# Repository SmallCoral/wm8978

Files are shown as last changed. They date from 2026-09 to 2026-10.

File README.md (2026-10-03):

# WM8978 USB 声卡

基于 **ATSAMD21E18A** 和 **WM8978** 的 USB 音频硬件项目，目标支持 **48 kHz / 16-bit 全双工音频**，提供耳机播放、麦克风采集和扬声器输出。

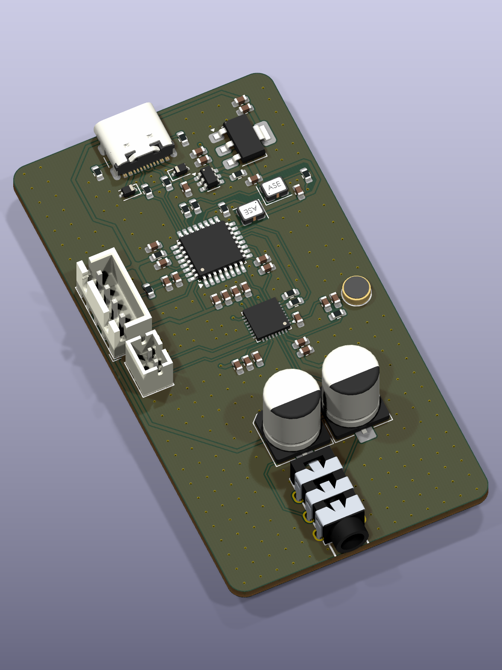
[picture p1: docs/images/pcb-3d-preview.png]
PCB 3D 预览


## 硬件特点

- USB-C 供电与通信，包含 ESD 保护、限流和 3.3 V 稳压。
- SAMD21 与 WM8978 通过 I²S 传输音频，通过 I²C 配置 codec。
- 独立的 12 MHz 主控时钟与 12.288 MHz 音频时钟。
- 立体声耳机输出、驻极体麦克风输入、BTL 扬声器输出及 SWD 调试接口。
- 提供 KiCad 原理图、PCB、自定义库和项目 3D 模型。

## 打开工程

安装 **KiCad 10** 及其标准符号、封装和 3D 模型库，然后打开 [WM8978.kicad_pro](pcb/WM8978.kicad_pro)。项目自定义库与模型使用相对路径。

## 目录

| 目录 | 内容 |
| --- | --- |
| [pcb/](pcb/) | KiCad 工程、原理图、PCB 与器件库 |
| [scripts/](scripts/) | 原理图检查、PCB 同步与模型处理脚本 |
| [reports/](reports/) | 设计复核记录与导出资料 |

## 项目状态

目前处于硬件验证阶段，USB 音频固件与实板测试尚未完成。

[原理图预览](reports/project-snapshot/2026-09-23/WM8978.pdf) · [设计检查记录](reports/footprint-binding/2026-10-03/review.md) · [3D 模型说明](pcb/WM8978.3dshapes/README.md)

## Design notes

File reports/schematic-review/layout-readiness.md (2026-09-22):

# Layout 前设计复核 · 2026-09-22

**此报告对应此前的原理图版本。** 后续文件已变化，最新复查发现 MCLK 断网，ERC 为 1 错误、1 警告；当前结论与证据见 [recheck-current.md](recheck-current.md)。以下“连接通过”和旧文件哈希仅适用于历史版本。

结论：原理图的连接检查通过，可以开展模块预布局；目前不建议直接冻结原理图并完成布线。应先解决 CN2 封装机械孔缺失，确定关键器件实物型号与封装，并明确 MCU 硅版本、上电浪涌和时钟负载。下文区分已发现的问题与尚待验证的风险。本轮未修改原理图、封装库或 PCB。

## 已通过的检查

- KiCad 10.0.5 原生 ERC：0 错误、0 警告，沿用现有规则。
- 200 项网表/参数检查通过，覆盖 MCU、USB、音频、供电和旧网络连接对比。
- 48 个器件的封装均可找到；符号引脚编号与封装电气焊盘编号集合全部对应。见 `layout-pad-check.json`。此检查不证明机械尺寸、定位孔或焊接工艺正确。
- 本轮审查对象原理图 SHA-256：`8368a36561a5d1e1f5fe6f73df535474cd44316d12db75493afdf71000d47e18`。
- PCB SHA-256：`fe49a5879a41e8960b2d1fa32fe4746d4188ac50d7024b465eacbf6cd71d87dd`，与修改原理图前一致。旧 STM32 PCB 仍不能代表本方案。

## Layout 前应解决或确定

### 1. CN2 定位孔缺失：已发现的封装问题

CN2 指定 `WM8978-import-fps:AUDIO-TH_PJ-3136-B`。当前封装有六个电气通孔焊盘，但没有机械定位孔；所附 XKB PJ-3136 图纸标有两个直径 1.60 mm 的定位孔。若采购该图纸所示器件，存在定位柱无法插入 PCB、器件不能贴板的风险。

应先按最终采购的 PJ-3136-B 图纸核对定位柱、引脚孔、插口相对板边的位置，再修正封装。不能只依靠焊盘 2/3/4 与符号对应来放行。

依据：[CN2 所附 XKB 原厂机械图](https://atta.szlcsc.com/upload/public/pdf/source/20231101/FB45AABFD04C0979FDEE8A028D0B6336.pdf)，PJ-3136 俯视图。

### 2. USB2、C86/C87、U16 的实物型号与封装尚未闭环

- USB2 只有通用 `USB_TYPE-C-16P` 封装，无可核对的制造商型号或图纸。不同 16P Type-C 座的固定脚、定位柱和舌片位置并不相同。先确定具体料号，再核对封装。
- C86/C87 为 220 µF / 16 V，分配 `CP_Elec_6.3x5.8`，但未给出有效的制造商型号。应落实容量、额定电压、直径、高度和推荐焊盘；若改变容量，需同步重新确认封装。
- U16 当前写 `WM8978GEFL/RV`，使用中心焊盘 3.1 × 3.1 mm 的通用 QFN。所引用 Rev 4.5 手册对应的更新订货码为 `WM8978CGEFL/...`，封装裸露焊盘 D2/E2 标为 3.30–3.60 mm。必须用实际订货后缀对应的机械图和推荐 land pattern 核对。器件裸露金属尺寸不等于 PCB 推荐铜皮尺寸，因此这里不能仅凭两者不同断言封装不可用。

依据：[WM8978 原厂数据手册 Rev 4.5](https://www.mouser.com/datasheet/2/76/WM8978_v4_5-1141768.pdf)，封装图与修订记录。

### 3. U1 必须避开不支持当前 I²S 架构的硅版本

本图是 WM8978 输出 BCLK/LRCLK，SAMD21 作为 I²S 从机。Microchip 勘误 DS80000760M §1.10.2、§1.10.4 指出：硅版本 A 的 I²S 不工作；硅版本 B 的外部 SCK/FS 从机模式不工作。型号 `ATSAMD21E18A` 中的末尾 A 并不是硅版本 A。

采购和固件验收应排除上述 A/B 硅版本，并通过 DSU.DID 确认。对于本型号，表中列出的后续硅版本为 C、D、H。C/D 的接收数据槽 RIGHT 对齐还有 §1.10.7 限制；建议统一使用 32-bit 时隙承载 16-bit 音频、BCLK = 64 × 48 kHz = 3.072 MHz，并按实际硅版本实施勘误规避。该对齐限制指 MCU 内部 SLOTADJ 配置，不能与 codec 的总线格式混为一谈。

依据：[Microchip SAM D21/DA1 勘误](https://ww1.microchip.com/downloads/aemDocuments/documents/MCU32/ProductDocuments/Errata/SAM-D21DA1-Family-Silicon-Errata-and-Data-Sheet-Clarification-DS80000760.pdf)，器件修订表及 §1.10。

### 4. USB 上电浪涌需要设计余量

直接接 VBUS 的 C75/C77/C92/C93 标称合计 9.6 µF，已经接近传统 USB 热插拔 10 µF 等效负载参考；3V3 端另有约 39.91 µF 的直接去耦容量，LDO 启动也会从 VBUS 取电。应考虑容差、直流偏压、LDO 启动和 codec 上电状态。

建议在电源入口预留/采用受控上升时间、合适限流值的负载开关，或通过计算和波形测量证明现有方案满足目标 USB 端口要求。直接挂在 VBUS 上的电容应留足余量。下游电容不能简单与输入电容相加判定违规；本项是尚未验证的浪涌风险。扬声器如需增加储能电容，宜放在受控电源之后，并核算压降和瞬态电流。

依据：[TI USB 电源分配应用说明 SLVA049](https://www.ti.com/lit/an/slva049/slva049.pdf)，10 µF / 44 Ω 热插拔负载及端口压降讨论。

### 5. Y1 的双负载时钟应核算驱动余量

Y1 ASE 系列规格列出的 CMOS 负载为 15 pF；WM8978 数字输入电容列为 10 pF，目前还同时驱动 MCU XIN，加上走线和焊盘寄生，余量需要确认。

现有 R73=33 Ω 可用于抑制边沿振铃，但不会消除容性负载。若无法证明满足 Y1 输出时序，选择更高负载能力的振荡器或加时钟缓冲器；若保留双分支，预留各分支源端串阻并缩短分支，首板测两端电平、边沿及过冲。增加串阻本身不能作为驱动能力不足的补救结论。

依据：[Abracon ASE 数据手册](https://abracon.com/Oscillators/ASEseries.pdf)及 [WM8978 数字输入规格](https://www.mouser.com/datasheet/2/76/WM8978_v4_5-1141768.pdf)。

## 建议的可选优化

| 改进 | 对本设计的价值与取舍 |
| --- | --- |
| U16 AVDD 支路预留 0 Ω / 磁珠位置 | 便于首板定位数字噪声耦合；配合芯片近端去耦，选择磁珠时检查压降和谐振。保持连续地平面，控制扬声器回流路径。 |
| BCLK、LRCLK 预留源端串阻 | 在 WM8978 输出端预留可调位置，可从 22–47 Ω 范围结合波形调整；短线不一定必须装高阻值。 |
| 增加调试测试点 | 5V、3V3、VDDCORE、RESET、MCLK、BCLK、LRCLK、SDA、SCL 及邻近 GND；高速时钟测试点采用小焊盘、短支路。 |
| 按耳机阻抗选择 C86/C87 | 理想一阶估算，220 µF 配 32 Ω 的截止频率约 22.6 Hz，配 16 Ω 约 45.2 Hz。若目标包括 16 Ω 耳机且重视低频，可选 470 µF，截止约 21.2 Hz；同时评估体积、容差和上电静音/爆音。 |
| 完整物料字段与保护方案 | 补齐 SW1 等器件 MPN、MLCC 耐压/介质及有效容量；按外壳和使用环境确定 VBUS、耳机接口保护。 |

## 放行条件与首板验证

正式 layout 前至少完成 CN2 封装修正、关键器件料号/封装确认、MCU 硅版本约束，并确定浪涌与时钟负载的处理方案。完成后可重新导出网表、跑 ERC 并进入完整布局布线。

现有方案尚无固件或实板证据。首板重点验证 USB 枚举/挂起/恢复、双向 I²S 连续收发、USB 音频速率匹配、扬声器最大工作点的电流和温升，以及麦克风底噪、耳机低频和爆音。原有 `review.md` 的连接检查结论仍有效，但不能替代本记录的 layout 放行条件。

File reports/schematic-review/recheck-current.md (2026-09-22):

# 当前原理图复查 · 2026-09-22

**结论：当前版本不能直接进入正式 layout。** 新发现 WM8978 的 MCLK 断网；CN2 耳机座的机械定位孔问题仍未解决。本轮为检查与记录，未修改原理图、PCB、封装库或项目设置。

## 本次重新执行的检查

- KiCad 10.0.5 重新导出当前网表，并执行原生 ERC：**1 个错误、1 个警告**，均由 codec MCLK 断网引起。
- 对比上次网表：排除旧 J1 / 新 J2 后，178 个共同引脚中，175 个引脚的连接组不变；另外 3 个引脚的差异全部属于同一处 MCLK 网络分裂。
- J2 的 4 个引脚单独检查通过：1=3V3/VTref、2=SWDIO、3=SWCLK、4=GND。
- 48 个器件的封装均存在，符号引脚与电气焊盘编号集合对应；SW1 新封装的两个焊盘也对应。该检查不覆盖机械定位孔及实际采购器件的尺寸。
- 已查看本次原生导出的整页图面，确认时钟源侧缺少网络标签。
- 旧 `scripts/check_schematic.py` 在 `U1.15 -> I2S_MCLK` 检查失败；它还使用旧 J1 接口约束，不能再把此前的“200 项通过”当作本版结论。

证据：`recheck-current-erc.json`、`recheck-current-netlist.xml`、`recheck-current.json`、`layout-pad-check.json`。

## 正式 layout 前的明确修正项

### 1. 恢复 R73 输出到 WM8978 MCLK 的网络

当前网表是：

| 网络 | 实际成员 |
| --- | --- |
| `Net-(U1-PA14)` | R73.2、U1.15 |
| `/I2S_MCLK` | 只有 U16.11 |

因此 Y1 经 R73 只给 MCU 提供时钟，codec 没有 MCLK；按本设计的 PLL / I²S 主机架构，音频时钟不能正常建立。ERC 对应 `pin_not_driven` 和 `isolated_pin_label`。

修正方式：在 **R73.2 至 U1.15 的导线上**恢复 `I2S_MCLK` 标签，使 `R73.2 / U1.15 / U16.11` 成为同一网络；不要用 PWR_FLAG 或忽略 ERC 消除提示。修正后重新导出网表、验证这三个引脚同网。

### 2. CN2 机械定位孔仍缺失

当前指定的 `AUDIO-TH_PJ-3136-B` 封装只有六个电气通孔焊盘，没有机械定位孔。CN2 所附图纸的 PJ-3136 视图要求两个 Φ1.60 mm 定位孔。按该图纸采购的带定位柱器件存在无法贴板安装的风险。

应按最终采购型号核对机械图并修正封装，核对插口与板边位置。[XKB 原厂图纸](https://atta.szlcsc.com/upload/public/pdf/source/20231101/FB45AABFD04C0979FDEE8A028D0B6336.pdf)

### 3. 落实关键实物料号与封装

USB2 仍只有通用 16P Type-C 封装，C86/C87 仍只有 220 µF / 16 V 参数而无有效制造商型号。应先确认实际接口机械尺寸、电解电容直径/高度/焊盘。

U16 仍写 `WM8978GEFL/RV`，使用中心焊盘 3.1 × 3.1 mm 的通用 QFN；引用的 Rev 4.5 手册包含更新的 `WM8978CGEFL/...` 订货码及封装图，应按实际后缀核对。封装裸露金属尺寸与 PCB 铜皮尺寸不能直接等同，不能仅凭名称判断兼容性。[WM8978 手册](https://www.mouser.com/datasheet/2/76/WM8978_v4_5-1141768.pdf)

## 设计改进建议

| 项目 | 建议及优先级 |
| --- | --- |
| 下载接口 | 当前 J2 四针信号接线正确，但没有 RESET。建议增加 RESET 引脚或紧邻接口的复位测试点，以便调试器控制复位；四针 SWD 本身并非接线错误。J2 实际封装是 JST XH 2.50 mm，自制转接线应按上述针序，不能只凭“JLINK”名称接标准排线。 |
| USB 上电浪涌 | VBUS 直接电容仍合计约 9.6 µF，3V3 端直接去耦约 39.91 µF。建议确认启动电流与主机端口要求，必要时增加限流/受控上升时间的负载开关。下游电容不能简单与输入电容相加判定违规。 |
| 时钟驱动 | 修复 MCLK 后，Y1 将恢复同时驱动两个芯片。ASE 规格负载为 15 pF，WM8978 数字输入电容列为 10 pF；需计入 MCU XIN 和走线寄生。若余量不足，应选择驱动能力更高的振荡器或缓冲器。串阻可改善振铃，不能代替负载能力核算。 |
| MCU 硅版本 | 当前 I²S 从机架构应排除 SAMD21 硅版本 A/B；型号末尾 A 不是硅版本。通过 DSU.DID 验收，按勘误处理数据槽对齐；32-bit 时隙承载 16-bit 音频是可采用的配置。 |
| 音频供电与调试 | AVDD 支路预留 0 Ω / 磁珠位置，保持连续地平面并控制扬声器回流；BCLK/LRCLK 源端预留可调串阻，增加电源及关键时钟测试点。 |
| 耳机低频 | C86/C87=220 µF 配 16 Ω 耳机的理想一阶截止约 45.2 Hz，配 32 Ω 约 22.6 Hz。若重视 16 Ω 耳机低频，可考虑 470 µF，同时核对体积和上电爆音控制。 |

供电、时钟和硅版本依据：[TI USB 热插拔负载说明](https://www.ti.com/lit/an/slva049/slva049.pdf)、[Abracon ASE 规格](https://abracon.com/Oscillators/ASEseries.pdf)、[WM8978 数字输入规格](https://www.mouser.com/datasheet/2/76/WM8978_v4_5-1141768.pdf)、[Microchip 勘误 §1.10](https://ww1.microchip.com/downloads/aemDocuments/documents/MCU32/ProductDocuments/Errata/SAM-D21DA1-Family-Silicon-Errata-and-Data-Sheet-Clarification-DS80000760.pdf)。

## 本轮文件基线

当前文件已经与上次审查版本不同，本轮保留用户的后续修改，没有回退 PCB。

| 文件 | 本轮开始及结束时 SHA-256 |
| --- | --- |
| 原理图 | `da9090cd18255e0a34c1a41e4236d26b039e8611c06d62f0447b395383ad4108` |
| PCB | `3dbe479590fec1b7c73a3aa50047f6be0c3d2642301092d8fa0e42d8cbf08127` |
| 项目设置 | `a735b4348fb94e4a48c6c9c1843c64e70f60052514bbe274a237ced6aaafd8e3` |

本轮未验证 PCB 布局布线、固件或实板。此前报告保留为历史记录；当前放行结论以本文件及对应 SHA-256 为准。

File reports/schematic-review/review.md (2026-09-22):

# 原理图复核记录 · 2026-09-22

后续 layout 审查发现了机械封装和器件版本等待解决事项，详见 [layout-readiness.md](layout-readiness.md)。本记录的 ERC/连接通过不代表已满足完整 layout 放行条件。

## 设计基线

工作开始时，用户已经删除旧 STM32 主控电路并放入未接线的 ATSAMD21E18A-A。
本次沿用该选择和现有 USB/WM8978 电路，未从 Git 恢复旧原理图。
保留所有原有器件 UUID，仅调整部分文字位置并补充主控外围。

原生 ERC 初检 45 项；最终 0 错误、0 警告。检查器仍使用原项目规则，没有新增排除或降低严重度。
原项目忽略的类别仍是 single_global_label、four_way_junction、simulation_model_issue、footprint_filter，详见 ERC JSON。

## 硬件修正

1. 完成 U1 的供电、所有地脚、USB FS、双向音频数据、I²C、复位和 SWD。
2. 新增 C97–C103、R70–R74、Y1、SW1、J1，共 15 个器件。
3. 使用独立 12 MHz 参考驱动 MCU XIN 和 codec MCLK，避免直接把 MCU 48 MHz 整数分频误当成 12.288 MHz。
4. 时钟 EN 接 PA18，100 kΩ 默认下拉；支持在切回内部时钟后关断振荡器。
5. 将 U16 的 MICBIAS 输出与 R68 偏置支路连通。原图标签仅存在于电阻一侧，没有给麦克风供电。
6. 更新主控名称、模块分区、说明及部分密集文字。原有 USB/音频器件位置和所有导线保持。

## 电气复核

| 项目 | 结论 |
| --- | --- |
| VDDIN、VDDANA | 同为 3V3，每组 100 nF + 10 µF |
| VDDCORE | 与 3V3 隔离，仅接 1 µF 对地；两个 GND 脚均连接 |
| 复位和调试 | RC 复位、330 Ω 按键串阻、SWCLK 1 kΩ 上拉；标准 Cortex SWD 针序 |
| USB | PA24=D−、PA25=D+；两侧触点并接正确，两路 CC 独立下拉，TVS 对地并联 |
| Codec 控制 | PA22/23 使用 SERCOM3 PAD0/1；4.7 kΩ 上拉；MODE=0，地址 0x1A |
| I²S | PA07=SD0 TX、PA08=SD1 RX；PA10/11 分别接 codec BCLK/LRC；同时收发 |
| 麦克风 | MICBIAS→R68→MIC1 正极；C79 接 LIP，C80 将 LIN 交流接地 |
| 耳机 | 两个 220 µF 电容正极朝向 codec，输出与直流偏置隔离 |
| 扬声器 | ROUT2 与 LOUT2 分别接负载两端，不接地；需固件配置 BTL 信号及反相 |
| 不使用的 codec 引脚 | 保留现有 NC，固件关闭不用的输入/输出通道 |

## 固件约束

- 启动顺序：OSC8M 启动 → PA18 置高 → 等待至少 2 ms → XOSC 外部时钟模式 → 配置 MCU/USB 时钟。
- USB 必须得到符合规格的 48 MHz 时钟并加载芯片 USB pad 校准值。
- WM8978 以 12 MHz 为 PLL 输入，参考参数 N=8、K=0x3126E9、PLLPRESCALE=0、MCLKDIV=/2；再选择 BCLK 分频、字长和 48 kHz 帧率。
- codec 为音频主机，SAMD21 的 serializer 0 发送、serializer 1 接收，共用 clock unit 0 的外部 BCLK/FS。不能把 PA07、PA08 都配置成输出。
- USB 主机 SOF 和板上音频参考并不锁相，需要异步反馈及持续的 DMA 缓冲管理；录音端也须正确管理每帧样本数。
- CSB 接地，不能把 GPIO1 配置为推挽高电平输出。
- 挂起时先使 codec 进入低功耗、MCU 切回内部时钟，再拉低 PA18。唤醒按相反方向建立时钟，并等待稳定。
- 未枚举和挂起时限制功耗，扬声器输出需按可用 USB 电流预算限幅。不能把 1 W 额定输出当作所有主机端口都允许的工作点。

## 检查证据

- `erc.json`：KiCad 10.0.5，所有错误、警告、排除项均纳入输出，违规数为零。
- `netlist.xml`：KiCad 从最终原理图直接导出。
- `connectivity-check.json`：200 项检查通过，包括关键引脚/参数、未使用 GPIO、完整旧电路连接对比。
- 旧连接对比允许的唯一网络合并：`R68.1 + U16.32 + C96.1`，对应 MICBIAS 修复。
- 原生 SVG 导出后另用原生 PDF/Poppler 做图面检查，检查了新增主控区和密集 codec 标注。
- PCB SHA-256：`fe49a5879a41e8960b2d1fa32fe4746d4188ac50d7024b465eacbf6cd71d87dd`，修改前后一致。
- 项目设置 SHA-256：`fc729af468ccccd9d76b9b11aee179896fd4961858aca257d9ce4f9314589901`，修改前后一致。

## 保留的实际验证事项

尚未运行固件或实板测试。USB 信号质量、ESD、挂起电流、LDO 温升、振荡器双负载与走线电容、
音频噪声和最大输出功率须在后续实板确认。现有 USB 外壳直连 GND，VBUS 无独立 TVS；
是否增加屏蔽 RC 或 VBUS 保护应结合外壳接地及产品 EMC 要求确定。
本次不更新 PCB；旧 STM32 PCB 和四份旧参考原理图均不代表当前正式电路。

器件与引脚依据见仓库 README 的厂商数据手册链接。

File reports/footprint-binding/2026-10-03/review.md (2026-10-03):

# 封装关联与原始 3D 模型补齐

2026-10-03 使用 KiCad 10.0.5 核对正式工程的 54 个实体器件，完成剩余关联，并用原始 CAD 替换此前生成的简化参考模型。

## 完成的修改

- C97、C98、C99、C100 的封装本身已经存在且与原理图选型一致，但原 PCB 缺少对应符号的 UUID 路径。本次补齐四条关联。
- Y1、Y2 使用 Abracon ASE 原厂 STEP，MIC1 使用当前封装关联的立创原库 STEP；这些下载文件未作修改。
- CN2 按用户确认的五脚版本保留现有五个金属插脚孔与两个定位孔。取得的原厂、原库 CAD 都有六个金属插脚，因此绑定立创原库的五脚适配模型：只切除多余中部插脚在安装面以下的部分，保留主体及触点细节，另存未经修改的六脚原库文件。适配文件不标为原厂五脚 CAD。
- MIC1、CN2 的项目封装库同步保存模型路径。Y1、Y2 使用项目库中的同名振荡器封装，焊盘及图形保持原样，后续更新封装时也能保留模型引用。
- 新增模型使用 `${KIPRJMOD}` 相对引用，文件随仓库保存。其余 50 个器件使用 KiCad 10 标准 3D 库。

详细来源、坐标偏移及适配范围见 [模型说明](../../../pcb/WM8978.3dshapes/README.md)。

## 验证结果

| 检查 | 结果 |
| --- | --- |
| 原理图封装字段、库文件、PCB 封装标识及符号关联 | 54 / 54 通过 |
| PCB 3D 模型路径 | 54 / 54 文件存在 |
| 三个原始 STEP 的字节与下载 SHA-256 比较 | 相同 |
| 三个原始 STEP 和一个五脚适配 STEP 重新读入 | 全部有效 |
| KiCad 原生 3D 渲染、整板 STEP 导出 | 成功，已检查显示与方向 |
| 整板 STEP 中 MIC1 / CN2 的板下金属引脚截面 | 2 / 5 根，与现有钻孔对齐 |
| 整板 STEP 中 ASE、CN2 的安装高度 | 正确 |
| 原理图完整网络及引脚集合与修改前比较 | 相同 |
| 35 项关键电路拓扑检查 | 全部通过 |
| 原生 ERC | 0 错误、0 警告 |
| 原生 DRC 未连接项 / 原理图一致性问题 | 0 / 0 |

模型替换以本地 KiCad 最新存档（2026-10-03 02:13:00，历史提交 `3530e5bf584c00aeff92c27b3be9be7ed7e63d87`）为布局基线。与该存档比较，全部原生几何相同：54 个封装、254 段走线、285 个过孔、3 个铺铜/禁铺铜区。文件语义比较确认，最新存档中的模型绑定、焊盘、网络、布线、板框、铺铜与工程规则均完整保留。此前的模型替换只修改 Y1、Y2、MIC1、CN2 的模型引用和偏移。

该最新存档相对上次 GitHub 提交已调整 C97、C98 的 X 坐标（分别从 127.76、126.25 mm 改为 129.00、127.49 mm），并将 R71 的 X 坐标从 123.25 mm 改为 124.75 mm，调整其 +3V3、SWCLK 走线及铺铜填充。这些已有布局调整一同保留。原理图相对上次 GitHub 提交仅改动 Y1/Y2 的封装库名称。

当前 DRC 仍有原先的 402 个错误、3 个警告，各类型及严重程度的计数与上次检查相同。关联及模型补齐不代表制造检查已经清零；原有规则与孔距、丝印事项见 [PCB 复核](../../pcb-review/2026-10-02-recheck-2347/review.md)。

原始模型及五脚适配后的 3D 预览

## 检查记录

- [封装关联](binding-audit-after.json)、[3D 模型路径](models-audit-after.json)
- [原始模型来源](original-model-sources.json)、[CAD 与原生整板 STEP 验证](original-model-validation.json)
- [五脚适配检查](five-pin-adaptation.json)、[模型绑定变更](model-binding-changes.json)、[修改范围验证](verification.json)
- [ERC](erc.json)、[DRC](drc.json)、[关键拓扑](topology-check.json)
- [原生网表](netlist.xml)、[几何数据](geometry.json)

源文件 SHA-256：

```text
PCB: 5fb48f70224364015cf48c9607fd8780e6c241d2294cacb238a3a9f37e3e6dfc
SCH: ec997bf1890f5b327d74b67f1542f2626916010a5ec2dfd338209763c5ab9a2f
```

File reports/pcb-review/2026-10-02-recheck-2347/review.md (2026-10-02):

# PCB 再次更新后复核 — 2026-10-02 23:47 版本

这版的主要布局修改有效：主控 VDDANA 去耦、codec 时钟输出串阻以及 QFN 底部局部接地都有明确改善，可以保留这些调整。整体功能分区和底层大面积地平面也可以保留。布局已更接近打样，剩下主要是供电路径优化和发板前的制造规则核对。

检查依据为 **2026-10-02 23:47:32 保存的 PCB**。本次仅生成报告，未修改 PCB、原理图或工程设置；三个源文件检查前后哈希相同。本轮使用 KiCad 10.0.5 原生 DRC，在内存中重新铺铜，没有保存回板文件。原理图和工程设置与上一轮内容相同。

## 已完成的改善

| 项目 | 上一轮 | 本轮 | 结论 |
| --- | --- | --- | --- |
| C99 100 nF 到 U1.9 电源脚 | 焊盘中心距离 14.75 mm | **1.71 mm** | 已移到主控右侧电源脚附近，位置明显改善，不再列为远离电源脚的问题。 |
| C100 10 µF | 距 U1.9 1.98 mm | **3.11 mm**，紧邻 C99 | 让 C99 更靠近电源脚的安排合理，不必仅为减小 C100 的直线距离再次交换位置。 |
| U16 BCLK 输出到 R75 之前的铜线 | 11.70 mm | **1.74 mm** | 串阻已靠近 codec 驱动端。 |
| U16 LRCLK 输出到 R76 之前的铜线 | 15.83 mm | **1.65 mm** | 串阻已靠近 codec 驱动端。 |
| U16 QFN EP 内接地过孔 | 0 个 | **9 个** | 局部顶底层接地连接改善，不建议仅为增加数量继续堆孔；核对焊盘内过孔的装配处理。 |
| 未连接项目 / 原理图一致性问题 | 0 / 0 | **0 / 0** | 本轮 DRC 没有发现连接缺失或网表不一致。 |

当前 54 个封装、252 段走线、285 个过孔。C99、C100、R75、R76 和 C80 的位置发生变化；增加了局部地过孔并更新相应走线、地铜。

## 剩下的布局优化

| 优先级 | 位置 | 当前证据与建议 |
| --- | --- | --- |
| 较高 | **3V3 主干与 codec AVDD** | LDO 输出至 U16.31 AVDD 的铜线路径仍约 **138.25 mm**，到 U1.9 仍约 **95.19 mm**。建议改成更直接的主干与本地支路，减少沿板边及耳机电容外围绕行。这是几何路径估算，不能据此断言实板一定产生噪声或压降超标。 |
| 中 | **Y2/R73/C104 → U16 MCLK** | R73 到 U16.11 的铜线仍约 **25.64 mm**，包含两个过孔；Y2 到 R73 另约 4.13 mm。建议将这一组移近 codec 的数字输入侧、避开麦克风区域，同时保留连续地参考。该长度本身不是证明不能工作的依据。 |
| 中 | **C103 → Y1 电源脚** | C103 电源焊盘距 Y1.4 仍约 **6.46 mm**，可进一步靠近。Y1 到 MCU 的约 2.38 mm 时钟线可保留。 |
| 中 | **SPKVDD / BTL 与 codec 旁路** | SPKVDD 仍有靠近芯片的 0.2 mm 局部支路，两根 BTL 输出仍为 0.2 mm。按实际扬声器电流及铜厚核算后尽量加宽；C90、C92 的电源焊盘距对应芯片脚约 5.37 / 5.26 mm，可进一步缩短本地去耦环路。 |

上轮 C99 和 R75/R76 的摆位问题已解决，不应继续把这些旧问题计入当前待改清单。U16 EP 接地过孔也已补上，下一步应确认焊盘内过孔与钢网/回流焊工艺配合。当前设置未声明塞孔或填孔，不能仅凭地孔数量认为装配工艺已经确认。

相关原厂依据：[SAMD21 数据手册的 Schematic Checklist](https://ww1.microchip.com/downloads/en/DeviceDoc/SAM-D21DA1-Family-Data-Sheet-DS40001882G.pdf)、[WM8978 数据手册](https://www.mouser.com/datasheet/2/76/WM8978_v4_5-1141768.pdf)、[Cirrus/Wolfson QFN 应用笔记 WAN_0118](https://statics.cirrus.com/pubs/appNote/WAN_0118_Rev_2.5.pdf)。

## DRC 与制造收尾

本轮原生 DRC 为 **402 个错误、3 个警告**，未连接和原理图一致性均为 0。错误类别与上一轮相同，新增的是一处 C80 与 U16 丝印重叠警告；并未新增普通铜间距违规。

| 类型 | 数量 | 当前证据与处理方式 |
| --- | --- | --- |
| 过孔外径不足 | 199 个错误 | 实际 **285 个过孔全部为外径 0.50 / 孔径 0.30 mm**，工程要求外径 ≥0.60 mm。DRC 列出的数量并不是实际全部违规过孔的数量。 |
| 过孔环宽不足 | 199 个错误 | 实际环宽 0.10 mm，工程要求 ≥0.15 mm。若沿用当前制造规则，应改为 0.60/0.30 mm 后复查间距；若选定板厂明确接受当前规格，再按其工艺能力修订规则。新增 EP 过孔也必须纳入核对。 |
| USB2 封装内部孔距 | 4 个错误 | PTH 地触点与 NPTH 定位孔间距 0.1944 mm，规则为 0.25 mm。核对实际采购的 USB4105-GF-A 图纸及板厂 PTH/NPTH 要求；确认几何及工艺允许后才能使用有依据的局部规则。 |
| CN2 丝印越板边 | 2 个警告 | 调整或裁掉越界丝印；接口实体伸出量按插拔及外壳配合判断。 |
| C80/U16 丝印重叠 | 1 个警告 | 新位置使 C80 外框与 U16 丝印重叠，重叠位置约 `(141.0,98.0) mm`。裁短对应丝印即可，未发现因此产生铜间距错误。 |

制造规则未落实前仍不建议直接发板。398 条过孔错误是重复的尺寸/环宽问题，不代表 398 种独立的电路缺陷。

后续工艺核对补充：按[嘉立创制造工艺要求](https://www.jlc.com/portal/1/serviceGuide)，双层板普通过孔支持内径 0.30 mm / 外径 0.50 mm。因此若选用该板厂相应工艺，可保留当前普通过孔尺寸，并将最小过孔外径、最小过孔环宽分别落实为 0.50 mm、0.10 mm；不必仅为当前 DRC 报错统一放大全部过孔。本次 GitHub 同步未修改 KiCad 工程规则，原始 DRC 结果仍对应检查时的 0.60 mm / 0.15 mm 要求。QFN 焊盘内过孔的装配处理仍需另行确认。

所有器件位号仍隐藏，尚无额外接口文字。发板前建议补必要的芯片位号、SWD 针序、扬声器 BTL 端标识和极性说明。底层地平面整体较完整，可以保留；本轮不建议为了 USB 线长的微小差异加蛇形线。

## 文件与范围

- [原生 DRC](drc.json)、[本轮测量](review-metrics.json)、[本轮与上一轮比较](comparison.json)。
- [当前顶层图](top.png)、[当前底层图](bottom.png)、[顶层 PDF](top.pdf)、[底层 PDF](bottom.pdf)。
- [供电路径估算](power-paths.json)：仅基于走线中心线与焊盘几何；`null` 表示该简化模型未解析出路径，不代表原生 DRC 判断未连接。本轮 DRC 未连接为 0。
- [检查前源文件哈希](source-sha256.json)、[上一轮报告](../2026-10-02-recheck/review.md)。

本轮没有重复运行原理图 ERC，因为原理图内容未改变；上轮原生 ERC 为 0 错误、0 警告。未进行实板音频、USB 信号、热性能或外壳配合测试。

PCB SHA-256：`6bab4104b9a4396aed0626787fb0733c4d03d5ecf8939795109a768cd1f0dbb1`。

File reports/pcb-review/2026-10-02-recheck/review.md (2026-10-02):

# PCB 更新后复核 — 2026-10-02

比上一版有改善，但仍建议完成下面的局部调整和制造规则核对后再发板。整体功能分区及底层大面积接地可以保留，无需整体重排。

本次检查的是 **2026-10-02 21:50:12 保存的 PCB**，使用 KiCad 10.0.5 原生 DRC、重新铺铜后的层图及实际焊盘/走线几何。仅生成检查报告，没有写入 PCB、原理图或工程设置；三份源文件检查前后的 SHA-256 一致。没有可检查的 KiCad 编辑窗口，未确认未保存内容。

## 本次已改善

| 项目 | 上一版 | 当前版本 |
| --- | --- | --- |
| C100 到 U1.9 VDDANA 的焊盘中心距离 | 10.28 mm | **1.98 mm**，移到主控右侧、靠近电源脚 |
| SDA/SCL 与地过孔的铜间距违规 | 2 项，来自 `(133,89) mm` 地过孔 | **0 项**，该地过孔已移除 |
| 未连接项目 / 原理图一致性问题 | 0 / 0 | **0 / 0** |
| 原生 DRC 错误 / 警告 | 404 / 2 | **402 / 2** |

当前为 54 个封装、253 段走线、253 个过孔。与上一版相比，只有 C100 的封装位置发生变化；移除了两个地过孔，修改了 C100 连接及地铜轮廓。原理图、工程设置内容未改变，因此本轮没有重复运行原理图 ERC；上轮 ERC 的结果为 0 错误、0 警告。

## 建议先完成的修改

| 优先级 | 位置 | 当前证据与建议 |
| --- | --- | --- |
| 高 | **C99 → U1.9/10** | C99 是 100 nF，电源焊盘距 U1.9 仍约 **14.75 mm**。C100 移近是有效改善，但本地高频旁路仍应由就近的 C99 配合完成。把 C99 移到 U1.9/10 附近，优先缩短电源脚—电容—地的环路，再安排 10 µF 的 C100。 |
| 高 | **R75/R76 → U16.8/7** | 两颗 33 Ω 电阻仍在 MCU 接收端附近；本设计 codec 为 BCLK/LRCLK 驱动端。串阻之前的铜线仍约 **11.70 / 15.83 mm**。若用于源端串联阻尼，应移近 U16 输出脚，再从电阻往 MCU 布线。 |
| 高 | **3V3 主干及 U16 AVDD** | 实际走线图中的 U15 输出至 U16.31 AVDD 最短铜线路径仍约 **138.25 mm**，到 U1.9 约 **95.19 mm**。从 LDO 建立更直接的供电干线和支路，把电源接到对应去耦及芯片引脚附近，减少沿板边、耳机电容外围的绕行。路径长度仅为几何估算，不代表已经测得噪声或压降。 |
| 中 | **Y2/R73/C104 与 C103** | R73 到 U16 MCLK 仍约 **25.64 mm**，包含两个过孔。建议将 Y2/R73/C104 靠近 codec 数字输入侧。Y1 到 MCU 的 2.38 mm 时钟线可以保留；Y1 旁路 C103 距其 VDD 焊盘约 **6.46 mm**，可再贴近。 |
| 中 | **U16 接地和功率路径** | QFN EP 内仍没有接地过孔，EP 中心距最近地过孔约 **4.51 mm**。建议在 EP 或其紧邻区域增加接到底层地的过孔，焊盘内过孔按装配工艺处理。SPKVDD 的局部 0.2 mm 支路及两根 0.2 mm BTL 输出仍可按扬声器电流、铜厚核算后加宽；C90/C92 等本地去耦可进一步靠近对应脚。 |

去耦位置依据 [SAMD21 数据手册的 Schematic Checklist](https://ww1.microchip.com/downloads/en/DeviceDoc/SAM-D21DA1-Family-Data-Sheet-DS40001882G.pdf)。WM8978 EP 接地及装配建议可对照 [WM8978 数据手册](https://www.mouser.com/datasheet/2/76/WM8978_v4_5-1141768.pdf) 和 [Cirrus/Wolfson WAN_0118](https://statics.cirrus.com/pubs/appNote/WAN_0118_Rev_2.5.pdf)。

## 发板前仍需处理的 DRC

| 类型 | 本轮数量 | 原因和处理方式 |
| --- | --- | --- |
| 过孔外径 | 199 个错误 | 实际 **253 个过孔全部为 0.50/0.30 mm**；工程最小外径为 0.60 mm。报告数量不等同于全部实际违规过孔数量。 |
| 过孔环宽 | 199 个错误 | 当前环宽 0.10 mm，小于工程最小 0.15 mm。沿用现有制造规则时，应改为 0.60/0.30 mm 并复查周围间距；若板厂明确接受当前尺寸，再据其能力修订规则。 |
| USB2 内部孔距 | 4 个错误 | PTH 地触点与 NPTH 定位孔间距 **0.1944 mm**，规则要求 0.25 mm。需对照 USB4105-GF-A 实际采购件图纸及板厂要求核对；确认几何和工艺允许后才能采用适当局部规则。移动普通走线无法解决封装内部孔距。 |
| CN2 丝印到板边 | 2 个警告 | 调整或删除越界丝印。连接器实体伸出是否合理应按插拔和结构要求判断，不必仅因丝印警告移动连接器。 |

这些错误多数是重复的过孔尺寸问题，不是 402 种独立设计缺陷；但在制造规则未落实前，不能据“全部已连接”直接发板。

## 可以保留和最后补充

底层 GND 整体较完整，应继续保留连续参考地。USB D+/D− 的短走线没有新增问题，本轮不建议因微小长度差加入蛇形线；实际阻抗仍取决于板厂叠层。上轮关于 R53/R54 装配值的核对建议仍适用，详见 [上轮报告](../2026-10-02/review.md)。

所有器件位号仍隐藏，尚无额外接口文字。建议至少补主芯片位号、SWD 排针定义、扬声器 BTL 端和必要极性标识。固定方式仍需与外壳配合确认。

本次结论是布局及规则复核，尚未验证实际板厂叠层、外壳、装配条件或实板的音频/USB性能。

## 复核文件

- [原生 DRC](drc.json)、[本轮测量](review-metrics.json)、[与上一版的比较](comparison.json)、[供电路径](power-paths.json)。
- [当前顶层图](top.png)、[当前底层图](bottom.png)、[顶层 PDF](top.pdf)、[底层 PDF](bottom.pdf)。
- [检查前源文件 SHA-256](source-sha256.json)；本轮脚本再次核对了三个源文件未变。

PCB SHA-256：`62d195dd3c062353bcaa066ac836e092f2f920b8582b82d5aec6441b4f7d257a`。

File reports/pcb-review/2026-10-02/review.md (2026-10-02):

# PCB 布局复核 — 2026-10-02

整体分区可保留，建议完成下列局部调整及制造规则核对后再发板。USB/电源在上方、MCU 居中、codec 与模拟输入输出在下方的方向合理；底层保留了大面积 GND，连接已完成。主要问题集中在去耦和时钟外围的摆位、过长的电源路径、过孔规则及接口标注。

本次仅检查及生成报告，未写入 PCB、原理图或工程设置。Windows 当前没有可检查的 KiCad 编辑窗口，因此依据磁盘上正式工程文件检查，没有确认任何未保存的编辑内容。

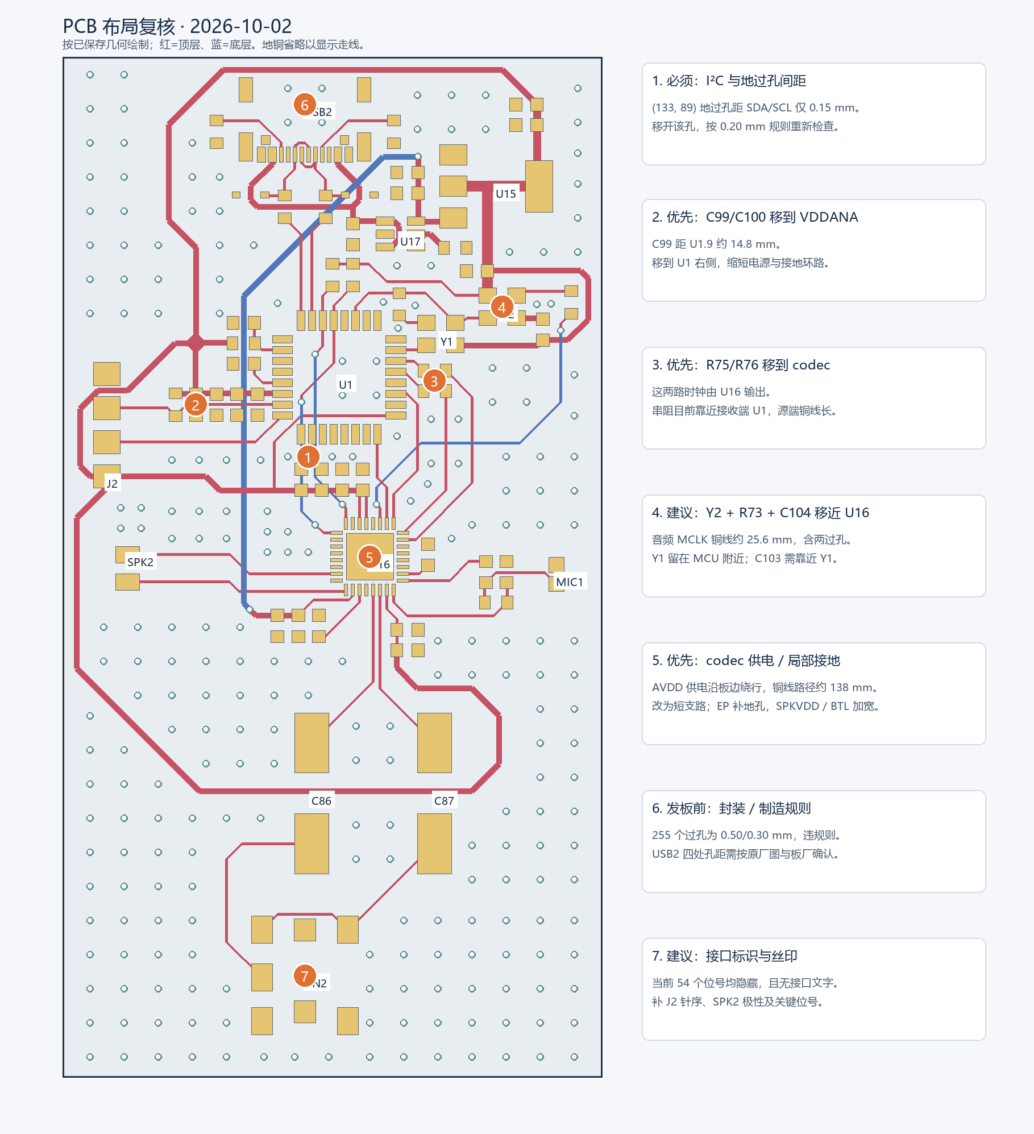
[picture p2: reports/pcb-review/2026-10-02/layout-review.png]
布局复核位置图


图中位置来自 `pcbnew` 对实际 PCB 的读取。红色为顶层走线，蓝色为底层走线；为显示走线路径，复核位置图省略了地铜，焊盘以简化外形表示。原生 KiCad 含地铜导出图见 [顶层](top.svg)、[底层](bottom.svg)。

## 已完成的检查

- KiCad 10.0.5 原生 DRC：报告列出 **404 个错误、2 个警告**；**0 个未连接项目、0 个原理图一致性问题**。
- 分别检查已保存铺铜与在内存中重新铺铜的结果，两份报告一致。没有使用 `--save-board`。
- 原生原理图 ERC：**0 错误、0 警告**；现有脚本的 **35 项关键拓扑检查通过**。
- 54 个封装、251 段走线、255 个过孔，2 层铜；1 个跨顶底层 GND 铺铜区与 2 个振荡器禁铺铜区。板框实体约 39.5 × 74.8 mm。
- PCB、原理图、工程设置的 SHA-256 在检查前后相同。

DRC 的数量大部分是同一类过孔尺寸问题重复产生，并非 404 种独立设计问题。不过仍不能直接忽略违规发板。

## 必须解决的规则问题

| 问题 | 实际证据 | 建议 |
| --- | --- | --- |
| 过孔直径与环宽 | 实际 255 个过孔全部为外径 0.50 mm / 孔径 0.30 mm，环宽 0.10 mm。当前工程要求外径 ≥0.60 mm、环宽 ≥0.15 mm。DRC 分别列出 199 条直径与 199 条环宽错误；几何统计显示全部 255 个过孔都需处理。 | 若沿用现有规则，统一采用 0.60/0.30 mm，并重新检查附近间距；若板厂确认可生产 0.50/0.30 mm，才将实际制造能力落实为项目规则。 |
| I²C 与地过孔间距 | `(133.000, 89.000) mm` 的 GND 过孔与底层 SDA、SCL 各有一处间距仅 0.15 mm，规则为 0.20 mm。 | 优先移动该地过孔；如果同时增大过孔直径，必须重新检查与两根线的距离。 |
| USB2 封装内部孔距 | PTH 地触点与两个 NPTH 定位孔间距 0.1944 mm，小于规则 0.25 mm，因重复地焊盘编号共报 4 项。定位孔中心为 `(129.860, 65.805)`、`(135.640, 65.805) mm`。 | 对照实际采购的 USB4105-GF-A 原厂图与板厂 PTH/NPTH 要求核对。确认几何正确且工艺接受后可设有依据的局部规则；否则调整连接器选型或封装。此项不能靠移动普通走线解决。 |
| CN2 丝印越板边 | 耳机接口前部有 2 条丝印被板边裁切。 | 调整或删除越界丝印；保留连接器为插拔所需的实体伸出量，不能仅根据丝印警告判断应移动连接器。 |

原始报告：[已保存状态 DRC](drc-saved.json)、[内存重新铺铜 DRC](drc-refilled.json)。

## 优先调整的布局

| 优先级 | 位置 | 现状与调整方向 |
| --- | --- | --- |
| 高 | C99/C100 → U1.9 VDDANA | C99 电源焊盘到 U1.9 中心距离约 **14.75 mm**，C100 约 **10.28 mm**。这组器件位于 U1 左侧，而 VDDANA 在右侧。将 C99 移到 U1.9/10 附近，C100 紧邻；100 nF 的电源、地环路优先最短。原理图上同属 3V3 不代表任意位置都能起到同样的高频去耦作用。 |
| 高 | R75/R76 → U16 时钟输出 | WM8978 是 BCLK/LRCLK 的驱动端，现有 R75/R76 位于 U1 接收端附近。U16 到串阻之前的铜线分别约 **11.70 / 15.83 mm**。将它们移到 U16.8/7 出脚附近，再从串阻往 U1 布线，以实现源端阻尼。 |
| 高 | 3V3 干线与 codec AVDD | 3V3 沿上边、左边、耳机电容外围有大段绕行。按实际走线中心线和焊盘连接建立图，U15 输出到 U16.31 的最短铜线路径约 **138.25 mm**；到 U1.9 约 95.19 mm。建议从 LDO 建立更直接的干线，分别接 MCU 和 codec 电源去耦，再进入对应引脚。AVDD 支路不宜为了避线而绕过整片耳机输出区域。此长度是几何路径，不是电源阻抗或噪声实测。 |
| 中 | Y2、R73、C104 → U16 | Y2→R73 铜线约 4.13 mm，R73→U16 MCLK 铜线约 **25.64 mm**，共约 29.77 mm，后半段含两个过孔及较大绕行。将这一组移近 U16.11，尽量在顶层短接，底层保留参考地。Y1 当前到 U1.XIN 约 2.38 mm，可保留。 |
| 中 | C103 → Y1 VDD/GND | C103.1 到 Y1.4 的焊盘中心距离约 **6.46 mm**。应把这颗旁路电容贴近 Y1 的电源和地；移动 Y2 时不要把 Y1 的本地旁路也带走。 |
| 中 | U16 EP 与电源外围 | EP 范围内没有地过孔，EP 中心到最近 GND 过孔约 **4.51 mm**。建议在 EP 或其紧邻区域补局部接地过孔，把顶层局部地直接接到底层地；焊盘内过孔与钢网开口按装配工艺共同设计。C90 到 DCVDD、C92 到 SPKVDD 的焊盘中心距离分别约 5.37 / 5.26 mm，均可进一步靠近，C83/VMID 也可缩短。 |
| 中 | SPKVDD、SPK2 BTL 输出 | SPKVDD 从限流器到 codec 的铜线路径约 53.71 mm，主干 0.4 mm，但靠近 C92/U16 有约 5.04 mm 的 0.2 mm 支路。两根 BTL 输出均为 0.2 mm、约 16 mm 长。建议按目标扬声器电流和铜厚核算，加宽到布局可容纳的宽度，短接本地去耦；0.4–0.6 mm 可作为此板普通支路的起点，并非已经验证的载流或温升结论。 |

SAMD21 手册明确要求去耦贴近每组电源引脚；串阻位置建议依据本设计的 codec 主机方向。WM8978 数据手册要求 QFN 地焊盘接模拟地，其引用的封装应用笔记说明了连接底层地的热过孔与钢网处理。[SAMD21 数据手册，Schematic Checklist](https://ww1.microchip.com/downloads/en/DeviceDoc/SAM-D21DA1-Family-Data-Sheet-DS40001882G.pdf)、[WM8978 数据手册](https://www.mouser.com/datasheet/2/76/WM8978_v4_5-1141768.pdf)、[Cirrus/Wolfson WAN_0118](https://statics.cirrus.com/pubs/appNote/WAN_0118_Rev_2.5.pdf)。

## 可以保留与补充的地方

USB D+/D− 当前同在顶层，R53/R54 到 MCU 的铜线分别约 8.01 / 7.93 mm，差值很小。这是一块全速 USB 板，优先保持短、并行、连续参考地，不需要为了微小长度差增加蛇形绕线。现有约 0.20 mm 线宽与约 0.60 mm 间隙没有在工程中形成差分阻抗规则；不能据此声称已经满足 90 Ω，需要按实际板厂叠层和相邻地铜核算。

R53/R54 当前为 22 Ω，另有一项装配值建议复核：Microchip 针对 SAMD21 的 PCB 指南说明 USB 接口已设计匹配阻抗，不需要额外串联终端电阻。建议保留封装作为可调位置，优先复核采用 0 Ω 的装配方案，再用 USB 波形/功能测试确认。此次没有改变电阻值或原理图。[Microchip PCB Layout and Manufacturing Recommendations](https://onlinedocs.microchip.com/oxy/GUID-D5B5915F-6907-409C-A6D9-F79690ACDCA3-en-US-1/GUID-05FBCAE8-7963-4832-B376-55381CE331FD.html)。

底层 GND 整体较完整，麦克风支路与 BTL 输出分别在 codec 两侧，这些可以保留。将振荡器移近 codec 时，应选数字输入侧，避开 MIC1/C79/R68 的麦克风区域；不要为了分离模拟、数字信号而切开公共地平面。

当前 54 个器件的 Reference 均隐藏，PCB 没有额外接口文字。建议至少补上 U1/U16/Y1/Y2 的位号、J2 的 `1=3V3 / 2=SWDIO / 3=SWCLK / 4=GND`、SPK2 的两个 BTL 端标识及接口名称。核对电解极性及 IC Pin 1 标识装配后是否可见。该板没有安装孔；如果外壳不夹持 PCB，插拔 USB/耳机时应考虑安装孔或其它固定方式。

## 检查范围与文件

复核依据现有工程规则、网表、几何及原生导出层图。没有板厂最终叠层、外壳尺寸、装配工艺和实板，所以本报告不构成 USB 阻抗、结构配合、EMC、热性能或音频噪声的实测放行。

- [关键测量](review-metrics.json)：距离与走线长度、DRC 汇总。
- [供电路径](power-paths.json)：中心线图上的最短铜线路径及各节点。
- [原理图 ERC](erc.json)、[关键拓扑检查](topology-check.json)、[网表](netlist.xml)。
- [布局复核图](layout-review.png)、[顶层原生图](top.svg)、[底层原生图](bottom.svg)。

检查前后 PCB SHA-256：`3a621aa976b9e6d46cc95d3be0e166d6ae6cbf437a97736656044bea74c3209e`。

原理图 SHA-256：`cd944a4fc81085c140cde708b9e082f911263f64c10db1757d9ac354f2b7d255`。

工程设置 SHA-256：`c25cbc2c5eb59b648f1bb117abb0c43329212f6a3464ddce4428503c85e12df0`。

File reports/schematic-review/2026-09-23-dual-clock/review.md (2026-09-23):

# 双时钟及精简版复核（2026-09-23）

正式原理图现有 **54 个实体器件**。Y1 12.000 MHz 只送 SAMD21 PA14/XIN；Y2 12.288 MHz 经 R73=33 Ω 只送 WM8978 MCLK，两个时钟输出在网表中相互隔离。C103、C104 分别旁路 Y1、Y2。Y1/Y2 的使能共用 PA18，R74 使上电默认关闭。原 U18 缓冲器及其输入下拉 R79 已删除。

WM8978 配置为 I²S 主机：12.288 MHz MCLK 直驱，PLL 关闭，`R6.CLKSEL=0`、`MCLKDIV=000`、`BCLKDIV=010`、`MS=1`，输出 48 kHz LRCLK 和 3.072 MHz BCLK（双声道 32-bit 时隙）。SAMD21 I²S clock unit 0 作为从机，用串行器及 DMA 收发。12 MHz 是 MCU 的外部参考；USB 所需 48 MHz 时钟由 MCU 时钟系统在固件中建立。两个时钟域异步，USB Audio 必须实现反馈及缓冲管理。

上轮精简删除 12 个测试点、R62/R72/R77/R80、SW1；本轮又删除 U18/R79，增加 Y2，C104 改为 Y2 旁路。耳机左右声道已对应 Tip=左、Ring=右；四针 SWD 接口保留。J2 符号收入项目本地库，消除对缺失的 SparkFun 符号库引用。

KiCad 10.0.6 原生检查结果：

- 原理图 ERC：**0 错误、0 警告**；[报告](erc.json)。
- 关键网表拓扑：**35 项通过**，包含两个时钟输出隔离、I²S、USB、电源和耳机声道；[检查结果](topology-check.json)、[网表](netlist.xml)。
- PCB：54 个封装，原理图一致性 **0 项问题**；[同步记录](pcb-sync.json)。现有 PCB **0 条走线、0 个铺铜区**。
- 整板 DRC：**4 处 USB2 封装内部孔距违规**（焊盘 A1/B12、A12/B1 与两个定位孔的实际距离 0.1944 mm，小于项目设置的 0.25 mm）；另有 **135 个未连接项目**。这些与布线/连接器封装规则有关，尚未放行制板；[DRC](drc.json)。

布局时把 Y2 和 R73 放在 WM8978 MCLK 附近，C104 靠近 Y2 VDD，并让 12 MHz 与 12.288 MHz 走线分开。USB2 的定位孔/焊盘几何应对照 GCT 原厂推荐图及板厂能力核实；不要单靠调低全板 DRC 规则消除四处违规。原理图 [SVG](WM8978.svg) 可直接查看。

资料：[Abracon ASE](https://abracon.com/Oscillators/ASEseries.pdf)、[WM8978](https://www.mouser.com/datasheet/2/76/WM8978_v4_5-1141768.pdf)、[SAMD21](https://ww1.microchip.com/downloads/aemDocuments/documents/MCU32/ProductDocuments/DataSheets/SAM-D21-DA1-Family-Data-Sheet-DS40001882.pdf)、[SAMD21 I²S 模式说明](https://developerhelp.microchip.com/xwiki/bin/view/products/mcu-mpu/32bit-mcu/sam/samd21-mcu-overview/peripherals/samd21-i2s-overview/)。

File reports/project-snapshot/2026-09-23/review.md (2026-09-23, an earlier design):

# 2026-09-23 工程快照

本快照包含当前 KiCad 工程、项目符号库和封装库、检查及同步脚本、历史检查报告，以及当前中文原理图 PDF。正式入口为 `pcb/WM8978.kicad_pro`，需要 KiCad 10.0 及标准库。

## 当前状态

- SAMD21E18A 与 WM8978 使用独立的 12 MHz、12.288 MHz 时钟，codec 为 I2S 主机。
- 9 处蓝色说明为中文，使用 KiCad 默认字体；已检查导出图的字形及排版。
- 54 个实体器件；14 个电阻与 25 个陶瓷电容均为 0603 英制（1608 公制）。
- C86、C87 的 470 µF / 16 V 电解电容保留 8 mm 罐体封装。
- 54 个原理图与 PCB 封装标识一致，所有连接引脚均有对应焊盘。

## 本次验证

- KiCad 原生 ERC：0 错误、0 警告，见 `erc.json`。
- 新导出网表的 35 项拓扑检查全部通过，见 `netlist.xml` 和 `topology-check.json`。
- PCB 与原理图一致性问题：0 项，见 `drc.json`。
- PCB 已有 89 段走线，尚无铺铜区，仍有 102 个未连接项目。
- USB2 封装内部仍有 4 处孔间距违规：实际 0.1944 mm，小于当前 0.25 mm 规则；需核对原厂机械图与制造要求。

这是开发中的硬件工程快照，尚未完成 PCB 布线，没有配套固件或实板验证。旧方案的独立参考图与历史报告保留各自日期和用途，不代表当前设计。

## 打包范围

ZIP 从本次 Git 提交生成，包含所有受版本控制的工程文件。沿用 `.gitignore`，排除本机历史缓存、编辑器状态、锁文件及旧编译输出；不打包 `.git` 目录。GitHub 仓库保留完整 Git 提交历史。

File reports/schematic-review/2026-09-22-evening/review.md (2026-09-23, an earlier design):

# 当前原理图复查 · 2026-09-22 晚

本轮审查当前 SAMD21E18A + WM8978 单页设计。原理图、PCB、项目设置和器件库均未修改，检查对象的 SHA-256 见 `baseline.json`。

结论：主要电气连接已贯通，没有再次发现 MCLK 断网；仍应修正耳机左右声道，并在继续相关布线前同步 USB2/CN2 的 PCB 封装。旧报告中的 MCLK 断线、PCB 全部为 STM32、缺少限流开关和时钟缓冲器等描述已经不适用于本版。

## 明确需要修改

### 1. 耳机左右声道互换

当前网表实际连接：

| 芯片输出 | 电容 | 插座端子 | 标准 TRS 声道 |
| --- | --- | --- | --- |
| U16.29 / ROUT1，右声道 | C86 | CN2.4 / Tip | 左 |
| U16.30 / LOUT1，左声道 | C87 | CN2.3 / Ring | 右 |
| GND | — | CN2.2 / Sleeve | 公共地 |

按 CN2 所附 XKB 图纸的 SCHEMATIC 和插座接触片位置，端子 2 为 Sleeve、3 为 Ring、4 为 Tip。应交换两个耳机输出支路，使 LOUT1 经隔直电容接 CN2.4，ROUT1 经隔直电容接 CN2.3；电容正极继续朝 codec。否则标准立体声播放的左右声道会颠倒。可以用固件交换样本补偿，但当前工程无固件，不应依赖未实现的补偿。

来源：[XKB PJ-3136 原厂图纸](https://atta.szlcsc.com/upload/public/pdf/source/20231101/FB45AABFD04C0979FDEE8A028D0B6336.pdf)。

### 2. PCB 尚未同步两处连接器封装

- USB2：原理图指定 `WM8978-import-fps:USB_C_GCT_USB4105_GF_A`，MPN 为 `USB4105-GF-A`；PCB 实际仍为 `WM8978-import-fps:USB_TYPE-C-16P`。两者的焊盘尺寸、相对位置和机械孔不同，并非只有名字不同。PCB 旧封装也没有新封装中的两个 0.65 mm 定位孔。应按最终 GCT 型号同步封装，再检查接口已有走线、板边及外壳位置。
- CN2：项目库已经改为五个电气通孔加两个 1.60 mm 非金属化定位孔；PCB 内嵌的同名封装仍是六个电气通孔、零定位孔。仅“从原理图更新 PCB”未必刷新同名封装几何，需要执行“从库更新封装”并检查孔位。

本轮核对了两端的实际焊盘数据，不是根据 README 推断。PCB 已包含本版 72 个器件，不能继续称为“全部旧 STM32 PCB”。除 USB2 封装字段外，器件值和封装标识对应；电气焊盘网名也一致（两个未连接网络的 `/` 与 `{slash}` 是导出转义差异）。这不代表 PCB 已完成布局布线或通过 DRC。

来源：[GCT USB4105 产品页](https://gct.co/connector/usb4105)、原理图和 PCB 当前文件。

### 3. 库引用及自动检查需要更新

KiCad 10.0.6 原生 ERC：**0 错误、4 警告**，没有新增排除项。绝对路径和项目目录下重跑结果一致。

- J2 的 `PCM_SparkFun-Connector` 符号库在当前配置中不存在。建议换成标准连接器符号，或将实际使用的符号纳入项目本地库。
- USB2、CN2、MIC1 的 `WM8978-import-fps` 封装库在当前 CLI 环境中未被 ERC 解析。项目 `fp-lib-table` 和对应文件实际存在、语法可解析，因此这里只能确认库解析警告，不能据此断言三个封装丢失或电路错误。应检查项目库加载，再验证清零；不要关闭检查项目掩盖警告。
- `scripts/check_schematic.py` 仍假设 `/3V3`、旧 J1、振荡器直接接 R73、没有串联时钟电阻和测试点。对本次新网表运行时，首先在 `U1.9 -> 3V3` 失败，原因是当前电源网名为 `+3V3`。旧“200 项通过”不适用于本版；修改检查器时应同时校正耳机声道预期，不能把当前反接固化为测试要求。

## 本版已解决或核对通过

- MCLK：`R73.2 / U1.15 / U16.11 / TP7.1` 同网。
- Y1 经 U18 缓冲后驱动 MCU XIN 和 codec MCLK；U18 的低有效 OE 接地、输入有 R79 下拉、VCC 有 C104 去耦。此前振荡器直接承受双负载的结构已调整。
- TPS2553：IN/EN 接 VBUS_RAW，OUT 给 LDO 和 SPKVDD，ILIM 经 R78 到地；FAULT 是开漏信号，经 R80 上拉到 3V3。C105=1 µF 是直接位于 USB 入口的电容，原有较大电容在开关之后。
- R78=61.9 kΩ、1% 时，按 TI §9.5.1 公式估算限流范围约 **378–480 mA**，典型 **425 mA**。因此图中连续总负载不超过 350 mA 的约束有余量；仍需实测扬声器峰值和 USB 插入时的电流波形。此限流值不等于主机已允许设备取用相同电流。
- SAMD21 电源与地脚、VDDCORE 独立 1 µF 去耦、USB D±、两路 CC 下拉、SWD 和 RESET 测试点连接正确。
- MCU 的 PA07/PA08 对应 I2S SD0/SD1，PA10/PA11 对应 SCK0/FS0，PA14 为 XIN；主控作为音频从机的接线成立。
- MICBIAS 已接到麦克风偏置支路；MIC1 正负极、输入耦合和 VMID 去耦连接正确。
- U16 的中心焊盘已选 3.45 mm，PCB 实际铜焊盘也是 3.45 mm，EP 接地。
- C86/C87 已选 Panasonic EEEFK1C471P、470 µF/16 V、8 mm 直径封装。470 µF 配 16 Ω 负载的理想一阶截止约 21.2 Hz；无需再次建议从 220 µF 增大容量。
- BTL 扬声器两端分别接 ROUT2、LOUT2，没有接地。

## 可选优化与后续验证

1. **优先验证供电与扬声器峰值。** 350 mA 是整板约束，扬声器峰值叠加 MCU/codec 电流可能先触发限流，导致供电下跌、失真或复位。先测量，再决定是否需要调整限幅、供电支路或受控电源后的储能容量。
2. **FAULT 可接到空闲 MCU 输入。** 当前只引到 TP12，适合测量；接入 MCU 可记录过流/过温事件并做静音处理。不是基本功能的必需条件。
3. **MCU 版本和固件必须兑现图中约束。** 按 DSU.DID 排除不支持本 I2S 从机结构的早期硅版本；32-bit 时隙承载 16-bit 音频，48 kHz、BCLK 3.072 MHz。应用需实现异步 USB 音频反馈与缓冲管理、挂起/恢复时钟顺序和枚举前限功耗。
4. **时钟与保护按板级测试优化。** R73/R75/R76 靠近各自驱动端；保持连续参考地。检查时钟两端波形、USB 插拔/ESD、挂起电流和 LDO 温升后再决定是否增添保护或调整阻值。

依据：[TPS2553 数据手册](https://www.ti.com/lit/ds/symlink/tps2553.pdf)、[SN74LVC1G125 数据手册](https://www.ti.com/lit/ds/symlink/sn74lvc1g125.pdf)、[Abracon ASE 数据手册](https://abracon.com/Oscillators/ASEseries.pdf)、[Microchip SAM D21 数据手册](https://ww1.microchip.com/downloads/en/DeviceDoc/SAM-D21DA1-Family-Data-Sheet-DS40001882G.pdf)、[SAM D21 勘误 §1.10](https://ww1.microchip.com/downloads/aemDocuments/documents/MCU32/ProductDocuments/Errata/SAM-D21DA1-Family-Silicon-Errata-and-Data-Sheet-Clarification-DS80000760.pdf)。

## 检查范围和证据

本目录 `erc.json`、`netlist.xml` 为本次 KiCad 原生输出，`baseline.json` 记录审查对象。另进行了当前 12 项关键拓扑断言（全部通过）、连接器机械孔检查、72 个原理图器件与 PCB 器件及电气焊盘网络比较，并查看完整原理图渲染及连接器图纸。

本轮没有运行整板 DRC，没有运行固件或实板验证。没有把 ERC 通过当作整机可投产证明。

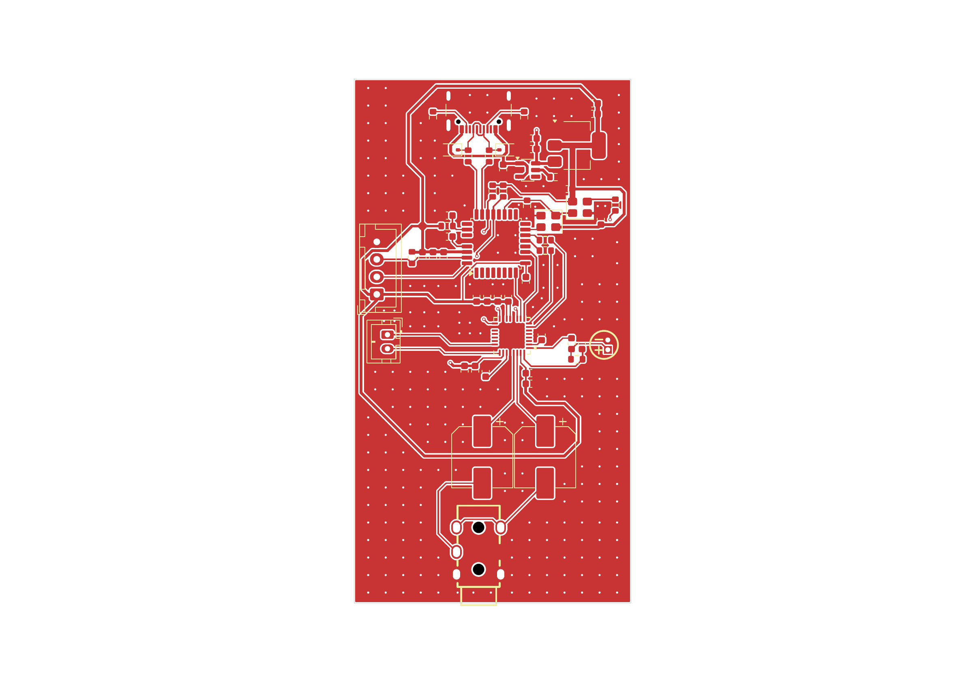
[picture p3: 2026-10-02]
reports/pcb-review/2026-10-02-recheck/top.png

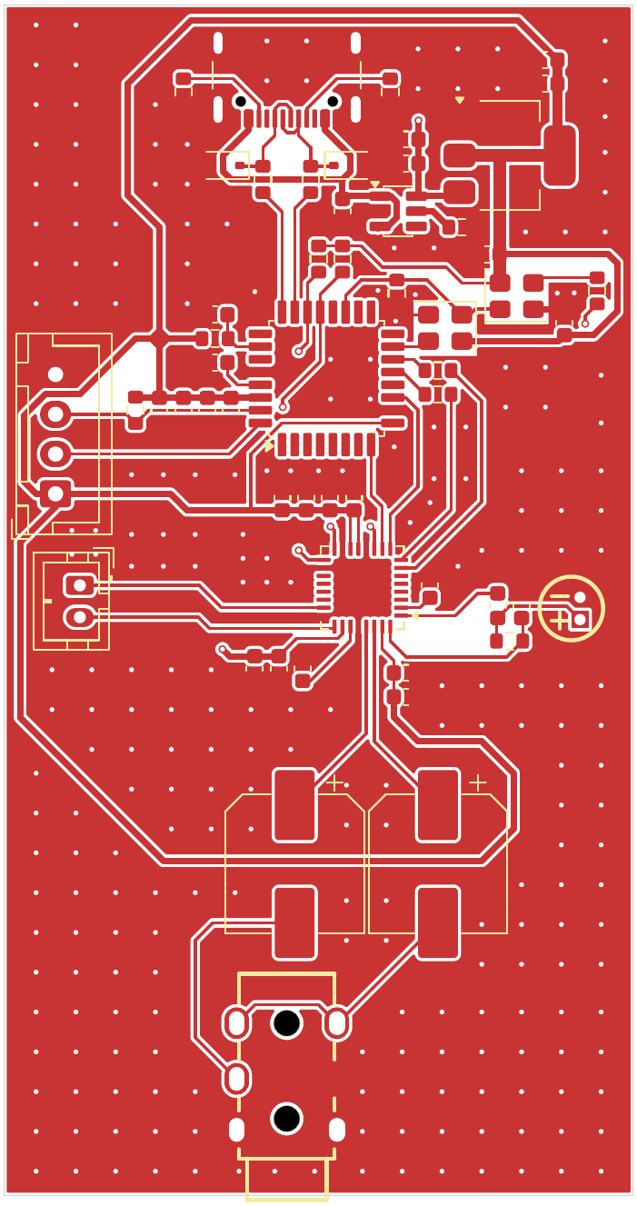
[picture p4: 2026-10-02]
reports/pcb-review/2026-10-02/top.png

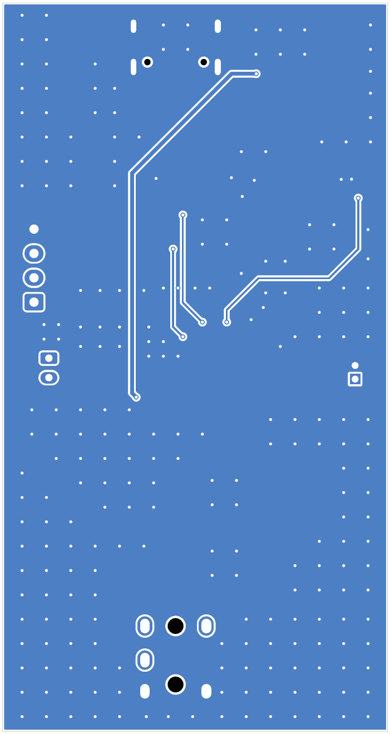
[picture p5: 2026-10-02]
reports/pcb-review/2026-10-02/bottom.png

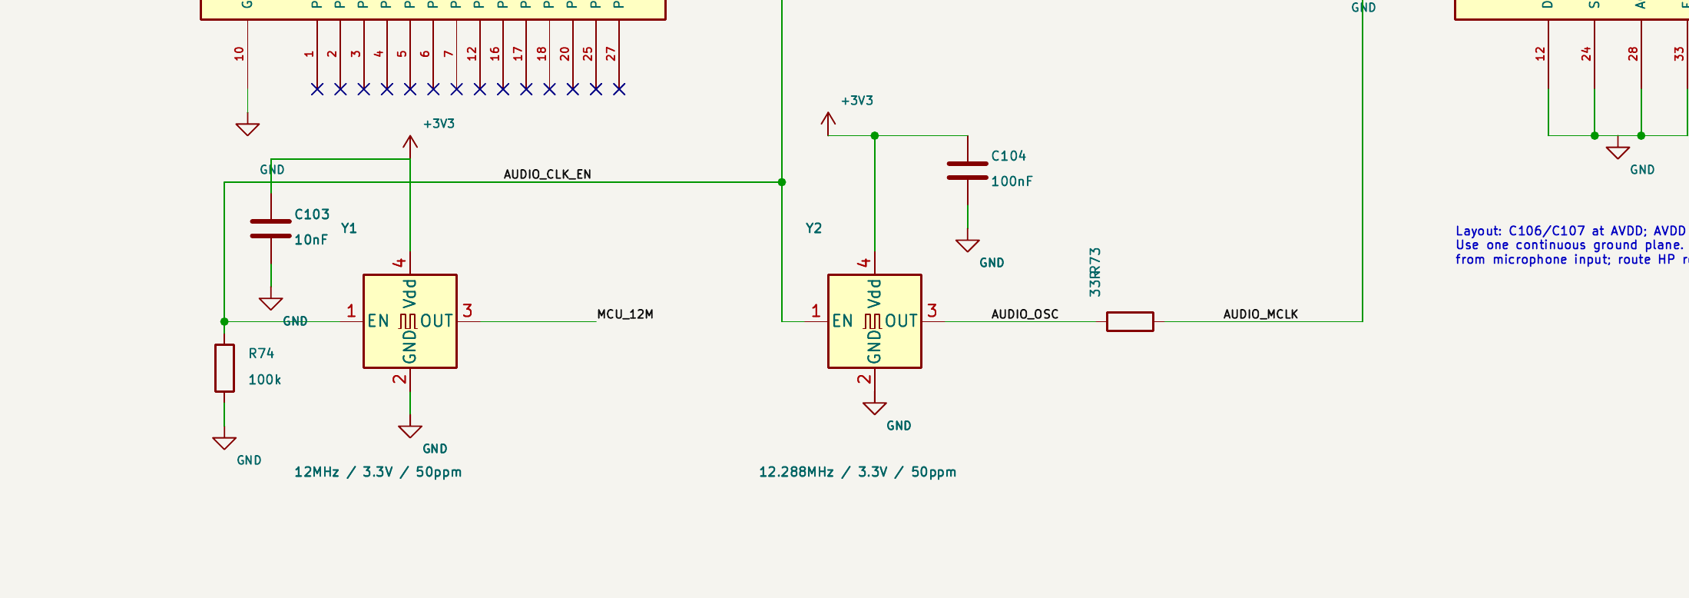
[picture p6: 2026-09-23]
reports/schematic-review/2026-09-23-dual-clock/dual-clock-detail.png

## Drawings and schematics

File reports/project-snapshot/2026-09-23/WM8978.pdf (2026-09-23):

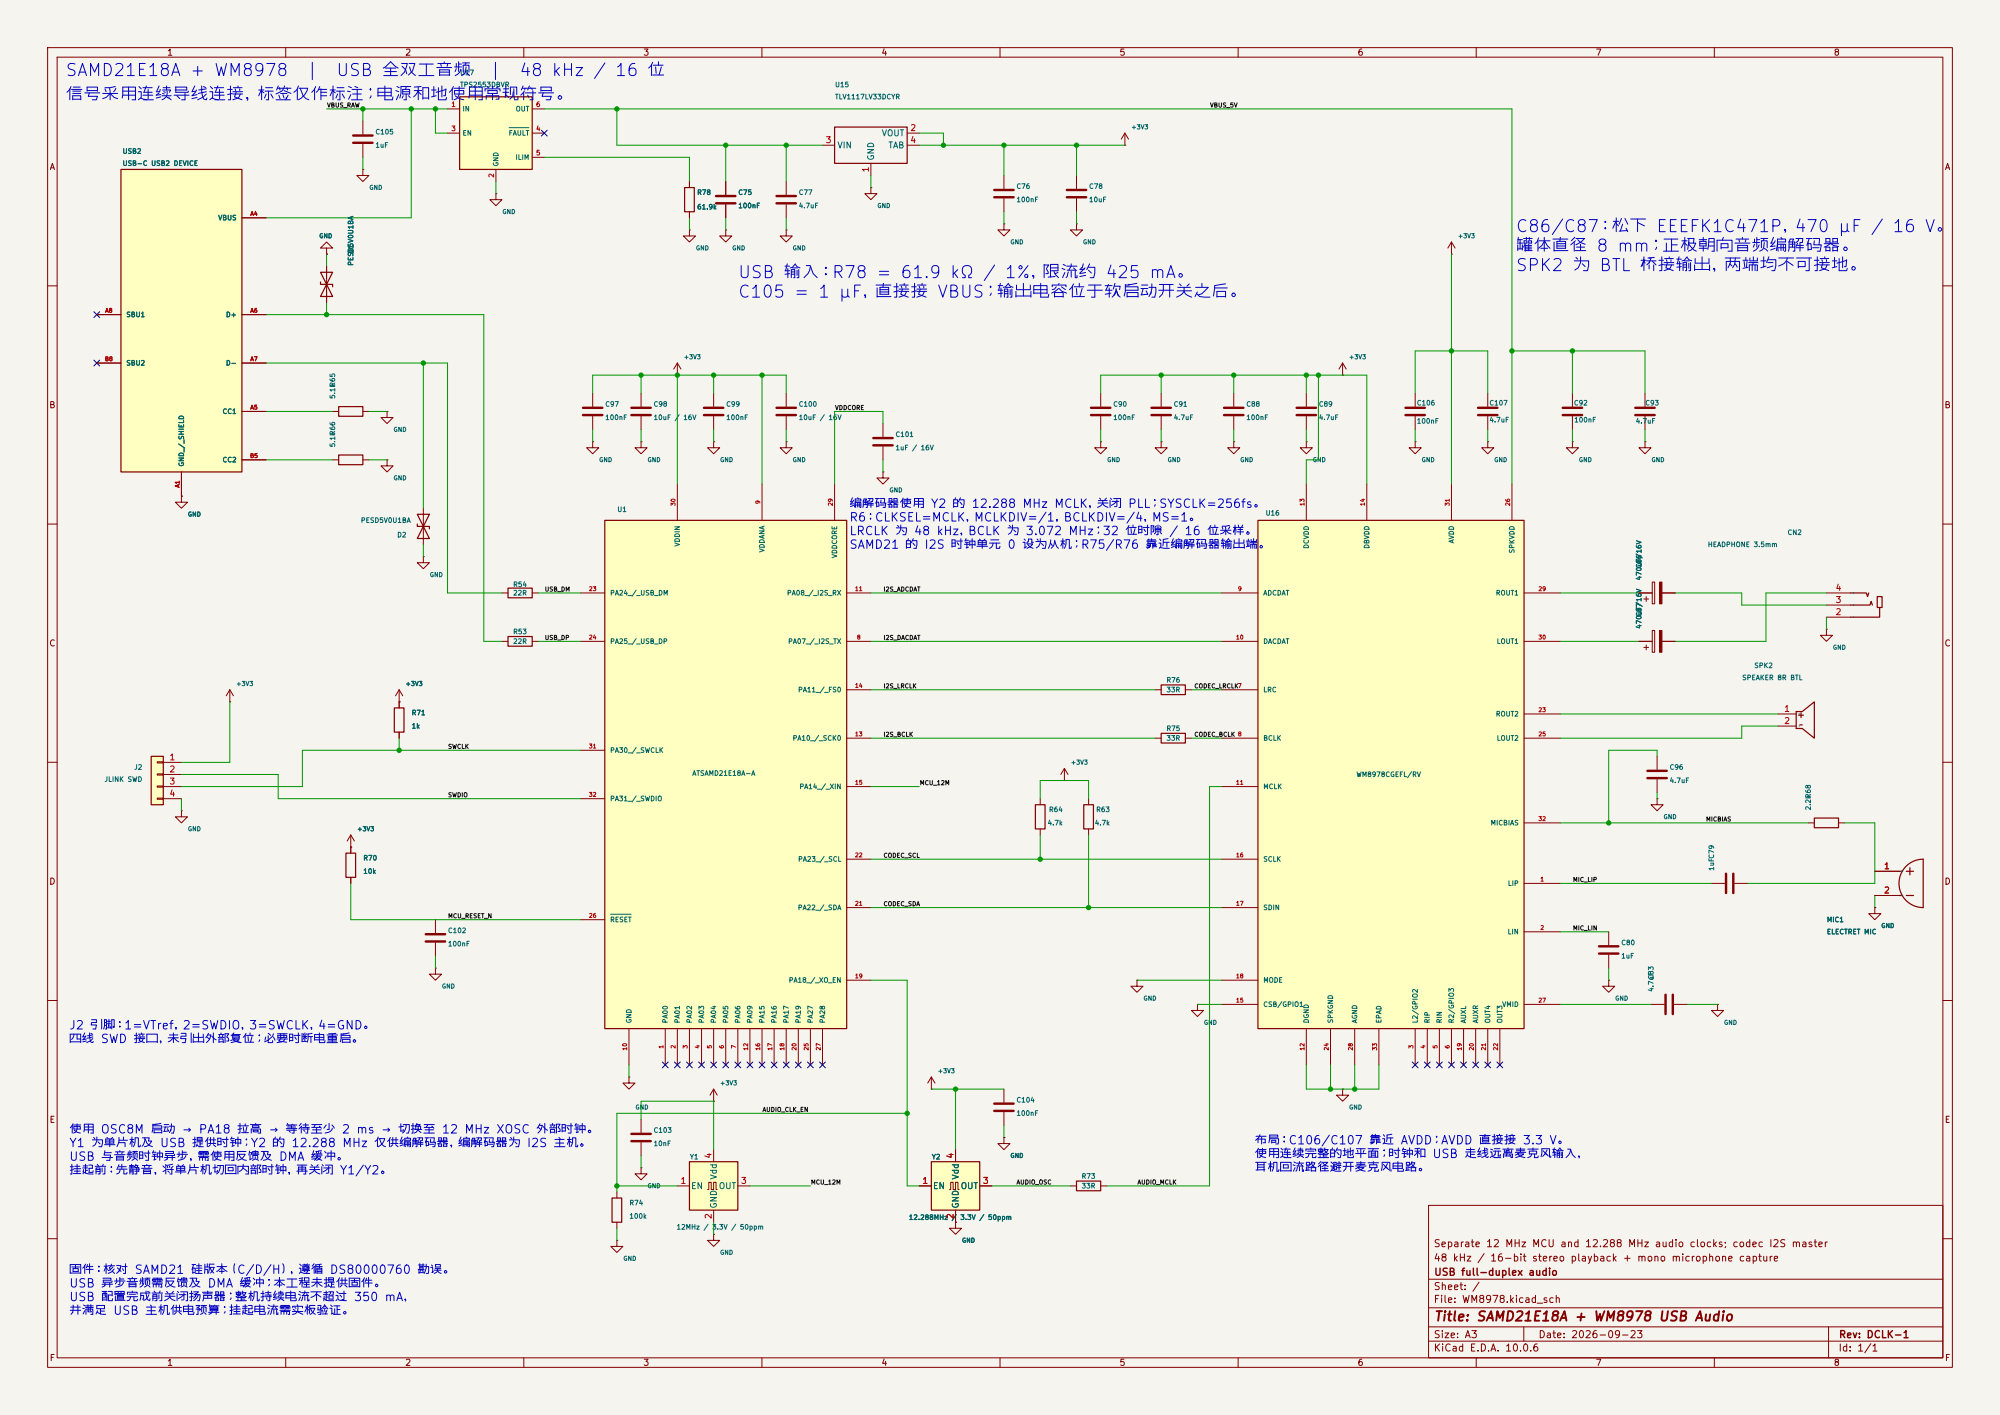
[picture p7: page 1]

GND
SPK2 为 BTL 桥接输出，两端均不可接地。 USB 输入：R78 = 61.9 kΩ / 1%，限流约 425 mA。
C105 = 1 µF，直接接 VBUS；输出电容位于软启动开关之后。

9 GND 10 PA08_/_I2S_RX 11 PA09 12 PA10_/_SCK0 13 PA11_/_FS0 14 PA14_/_XIN 15 PA15 16 PA16 17 PA17 18 PA18_/_XO_EN 19 PA19 20 PA22_/_SDA 21 PA23_/_SCL 22 PA24_/_USB_DM 23 PA25_/_USB_DP 24 PA27 25 RESET 26 PA28 27 VDDCORE 29 VDDIN 30 PA30_/_SWCLK 31 PA31_/_SWDIO 32 U1

编解码器使用 Y2 的 12.288 MHz MCLK，关闭 PLL；SYSCLK=256fs。
R6：CLKSEL=MCLK，MCLKDIV=/1，BCLKDIV=/4，MS=1。
LRCLK 为 48 kHz，BCLK 为 3.072 MHz；32 位时隙 / 16 位采样。
SAMD21 的 I2S 时钟单元 0 设为从机；R75/R76 靠近编解码器输出端。

6 LRC 7 BCLK 8 ADCDAT 9 DACDAT 10 MCLK 11 DGND 12 DCVDD 13 DBVDD 14 CSB/GPIO1 15 SCLK 16 SDIN 17 MODE 18 AUXL 19 AUXR 20 OUT4 21 OUT3 22 ROUT2 23 SPKGND 24 LOUT2 25 SPKVDD 26 VMID 27 AGND 28 ROUT1 29 LOUT1 30 AVDD 31 MICBIAS 32 EPAD 33 U16 WM8978CGEFL/RV

J2 引脚：1=VTref，2=SWDIO，3=SWCLK，4=GND。
四线 SWD 接口，未引出外部复位；必要时断电重启。

Separate 12 MHz MCU and 12.288 MHz audio clocks; codec I2S master +3V3
GNDC103

布局：C106/C107 靠近 AVDD；AVDD 直接接 3.3 V。
使用连续完整的地平面；时钟和 USB 走线远离麦克风输入，
耳机回流路径避开麦克风电路。

Y1 为单片机及 USB 提供时钟；Y2 的 12.288 MHz 仅供编解码器，编解码器为 I2S 主机。
USB 与音频时钟异步，需使用反馈及 DMA 缓冲。
挂起前：先静音，将单片机切回内部时钟，再关闭 Y1/Y2。

48 kHz / 16-bit stereo playback + mono microphone capture
USB full-duplex audio
Sheet: /
File: WM8978.kicad_sch
Title: SAMD21E18A + WM8978 USB Audio

固件：核对 SAMD21 硅版本（C/D/H），遵循 DS80000760 勘误。
USB 异步音频需反馈及 DMA 缓冲；本工程未提供固件。
USB 配置完成前关闭扬声器；整机持续电流不超过 350 mA，
并满足 USB 主机供电预算；挂起电流需实板验证。

Size: A3 | Rev: DCLK-1 | F Date: 2026-09-23
KiCad E.D.A. 10.0.6 | Id: 1/1

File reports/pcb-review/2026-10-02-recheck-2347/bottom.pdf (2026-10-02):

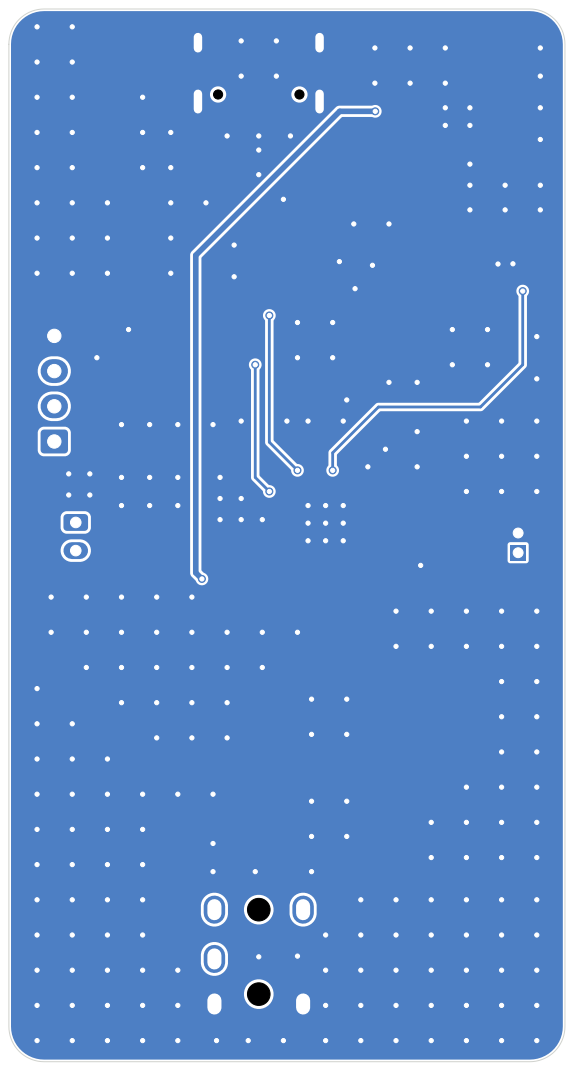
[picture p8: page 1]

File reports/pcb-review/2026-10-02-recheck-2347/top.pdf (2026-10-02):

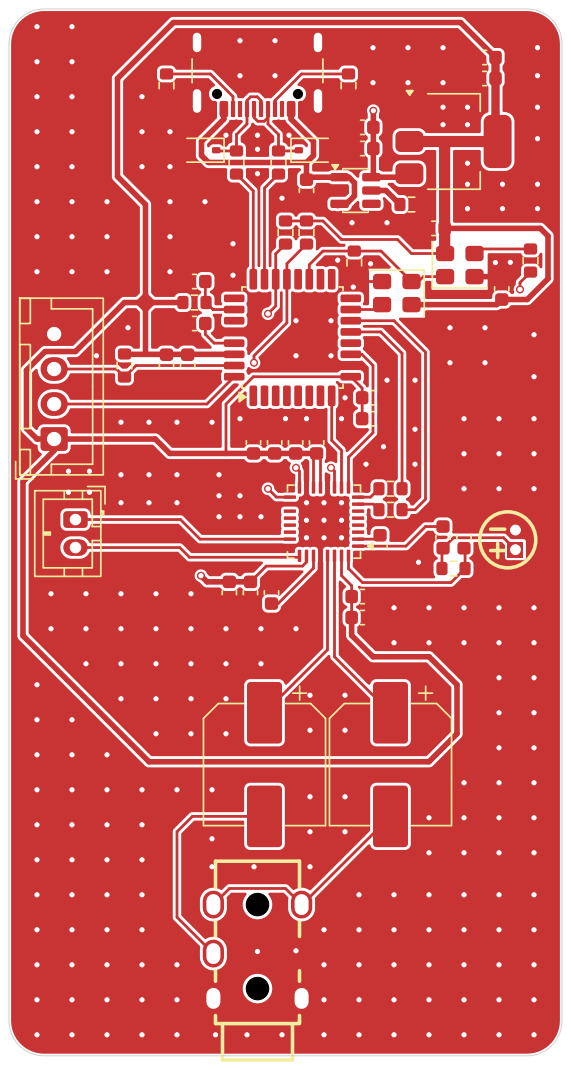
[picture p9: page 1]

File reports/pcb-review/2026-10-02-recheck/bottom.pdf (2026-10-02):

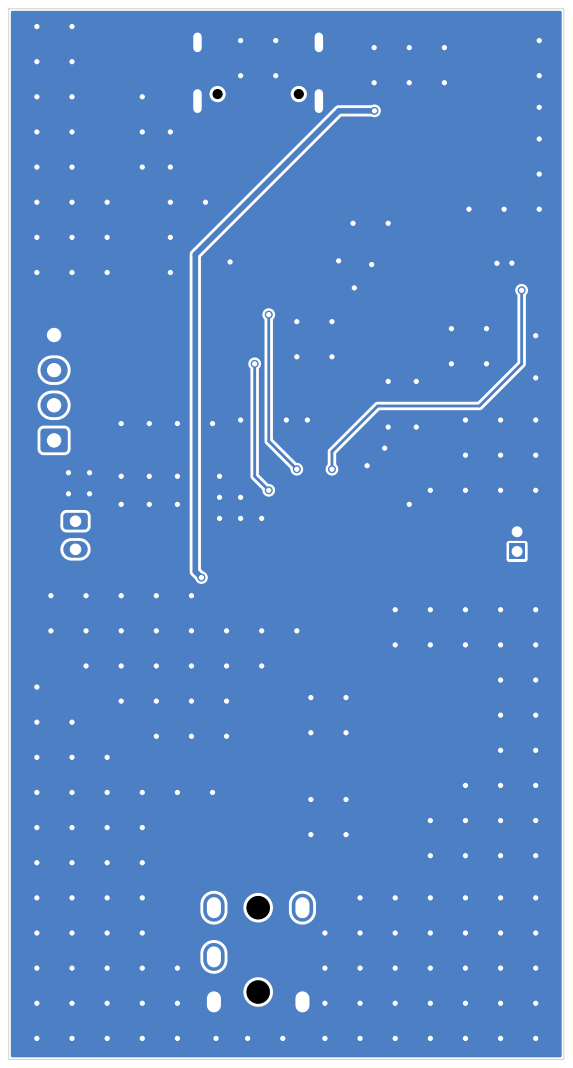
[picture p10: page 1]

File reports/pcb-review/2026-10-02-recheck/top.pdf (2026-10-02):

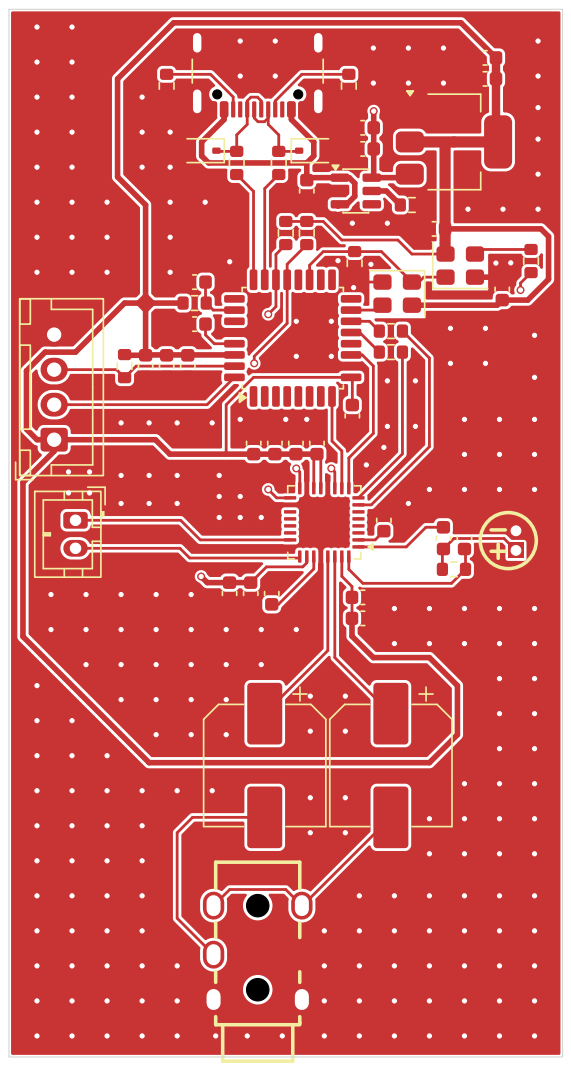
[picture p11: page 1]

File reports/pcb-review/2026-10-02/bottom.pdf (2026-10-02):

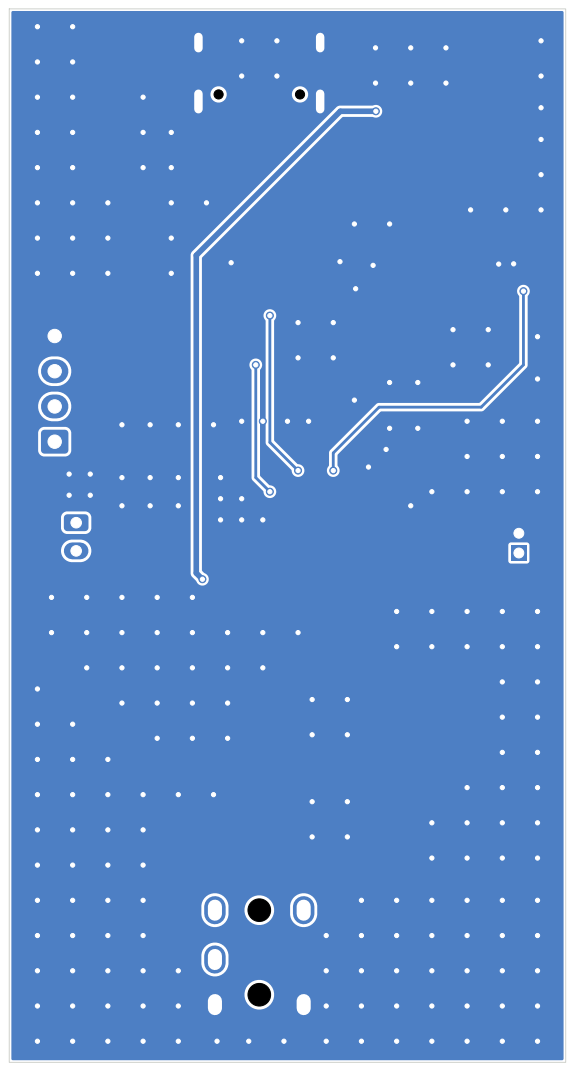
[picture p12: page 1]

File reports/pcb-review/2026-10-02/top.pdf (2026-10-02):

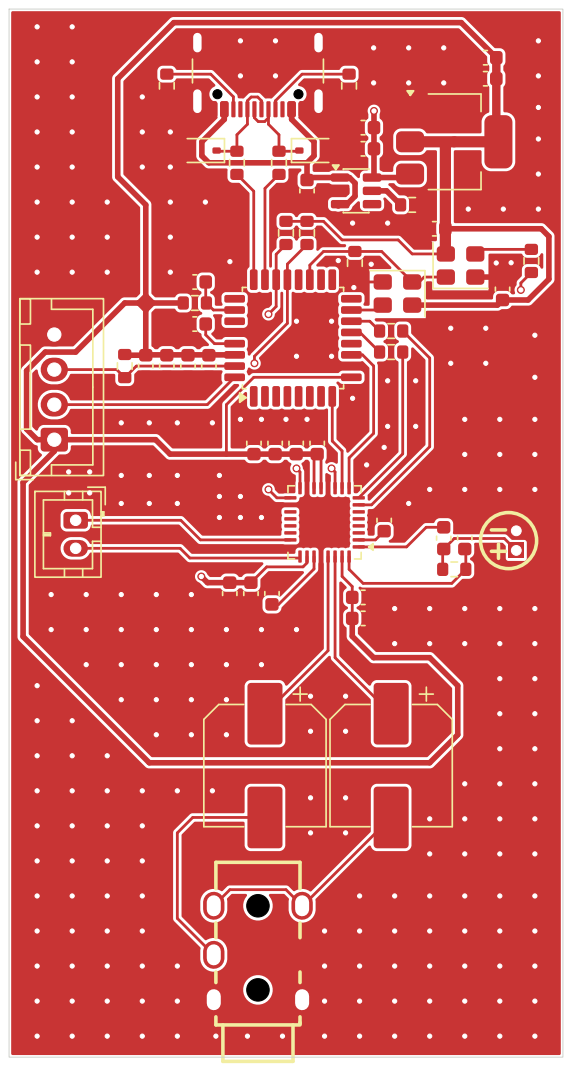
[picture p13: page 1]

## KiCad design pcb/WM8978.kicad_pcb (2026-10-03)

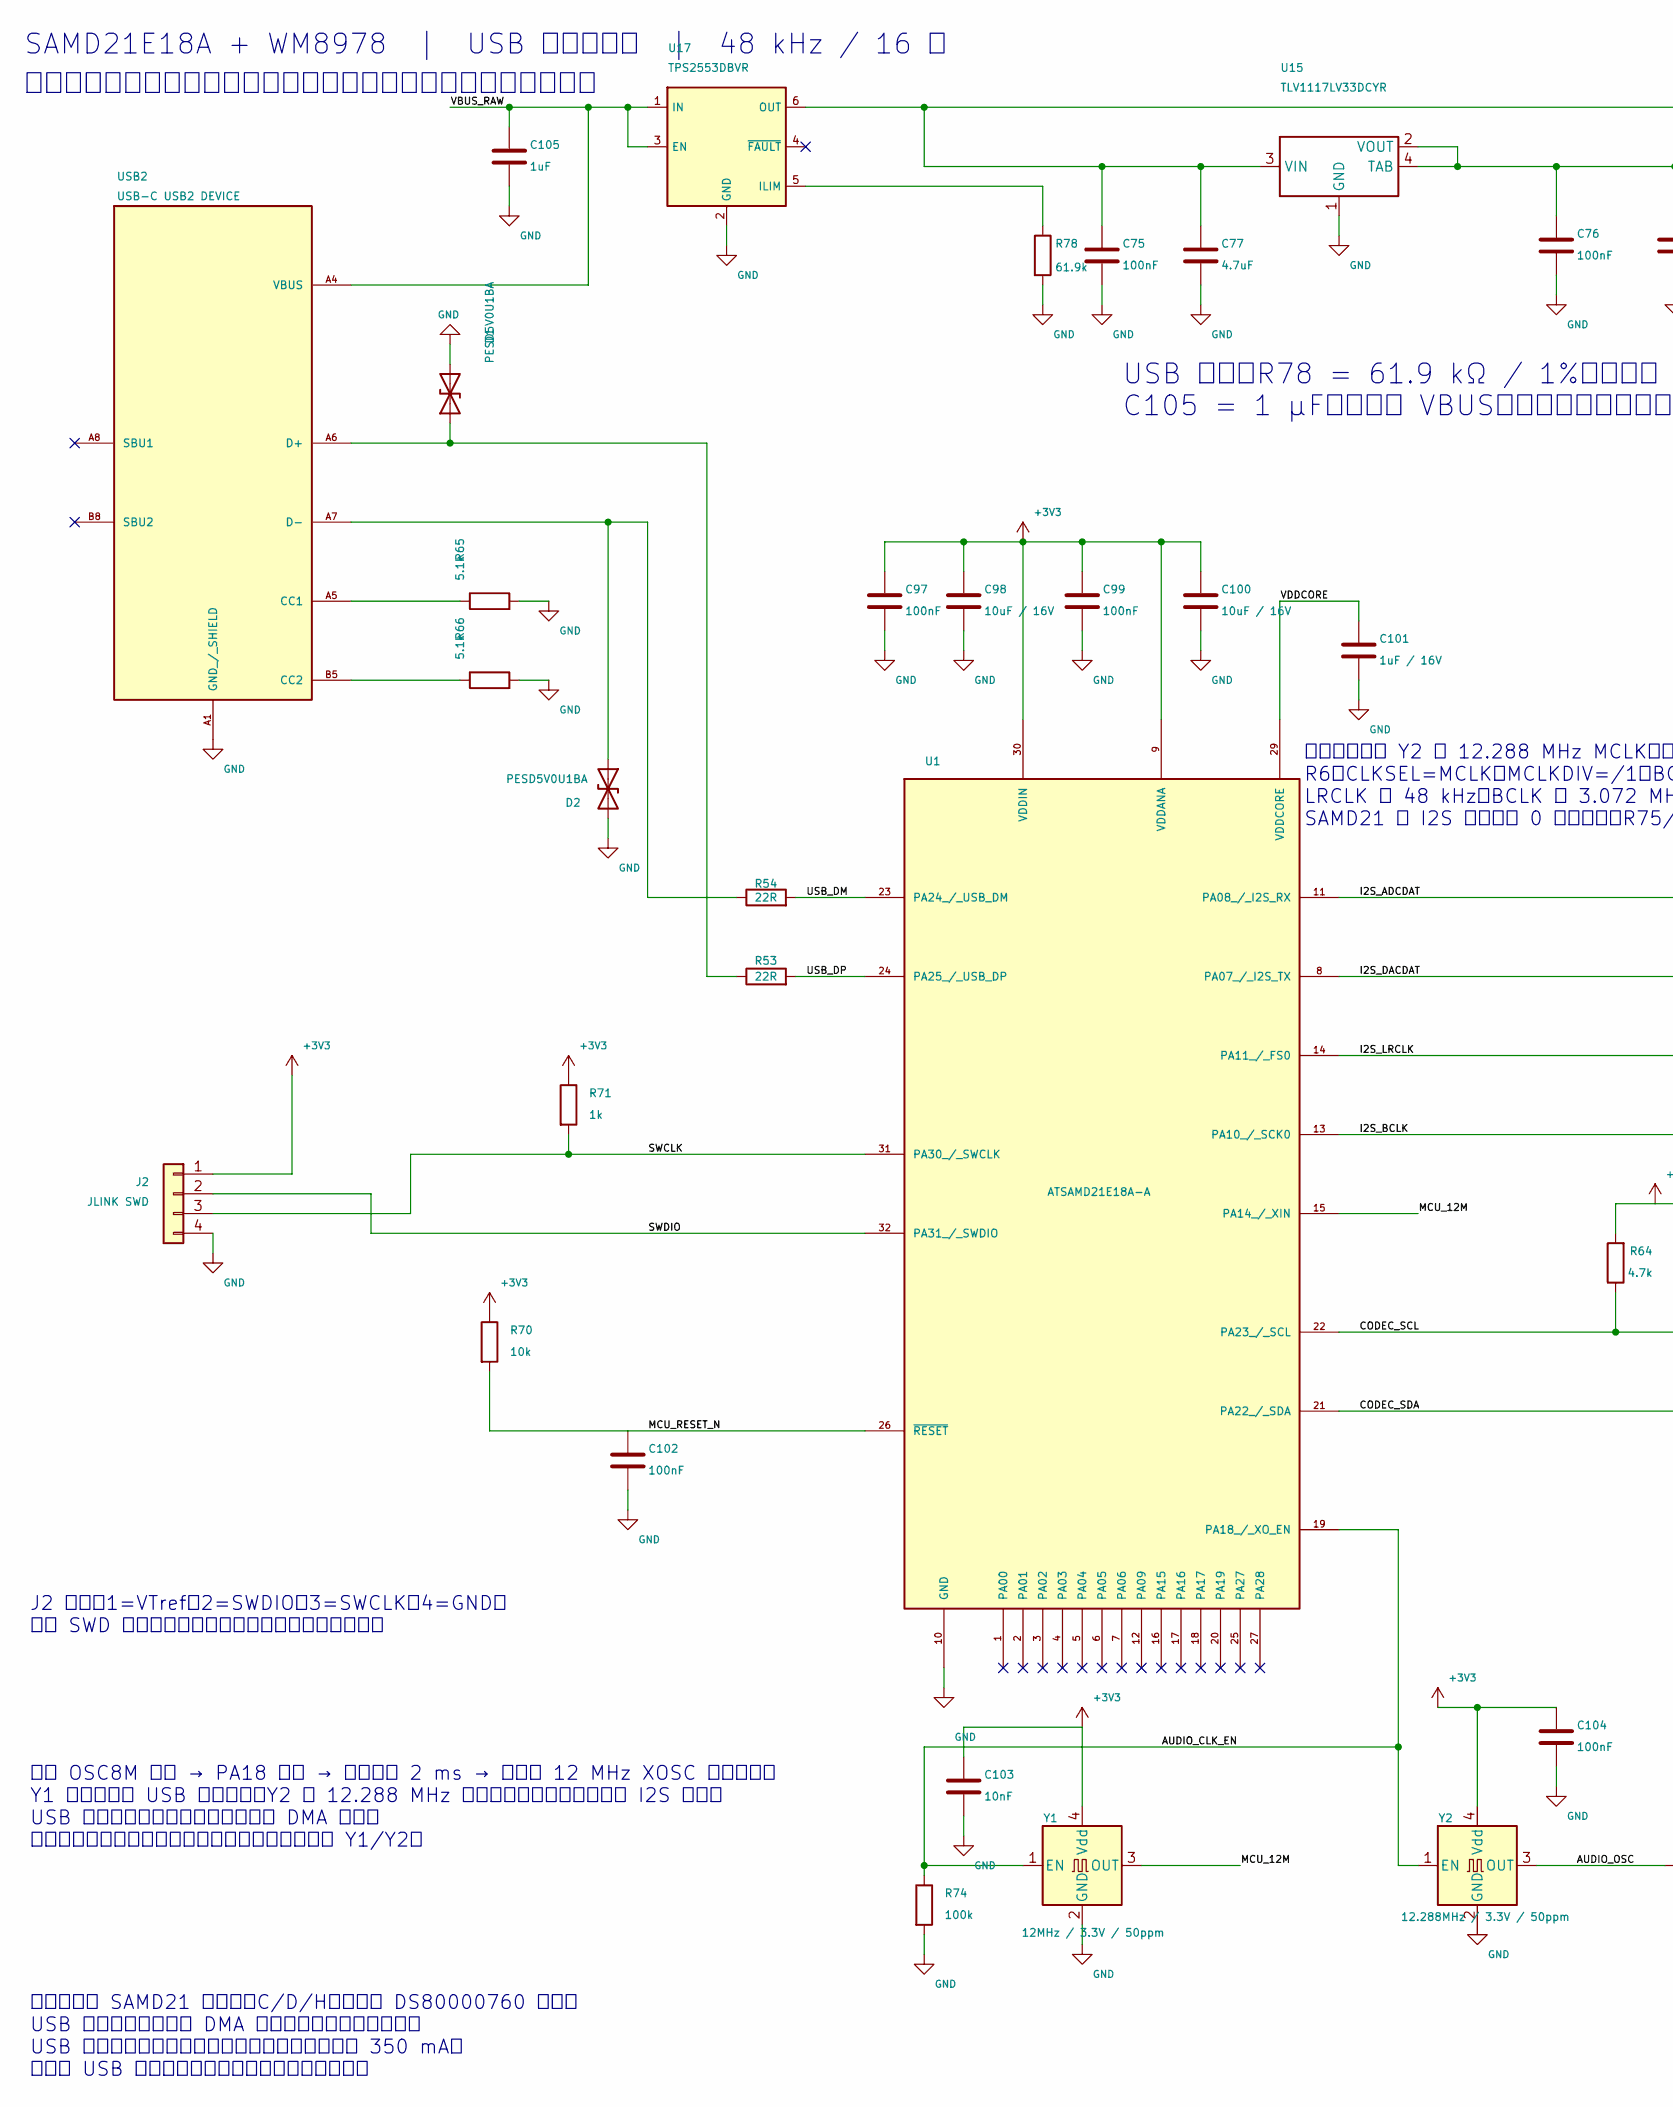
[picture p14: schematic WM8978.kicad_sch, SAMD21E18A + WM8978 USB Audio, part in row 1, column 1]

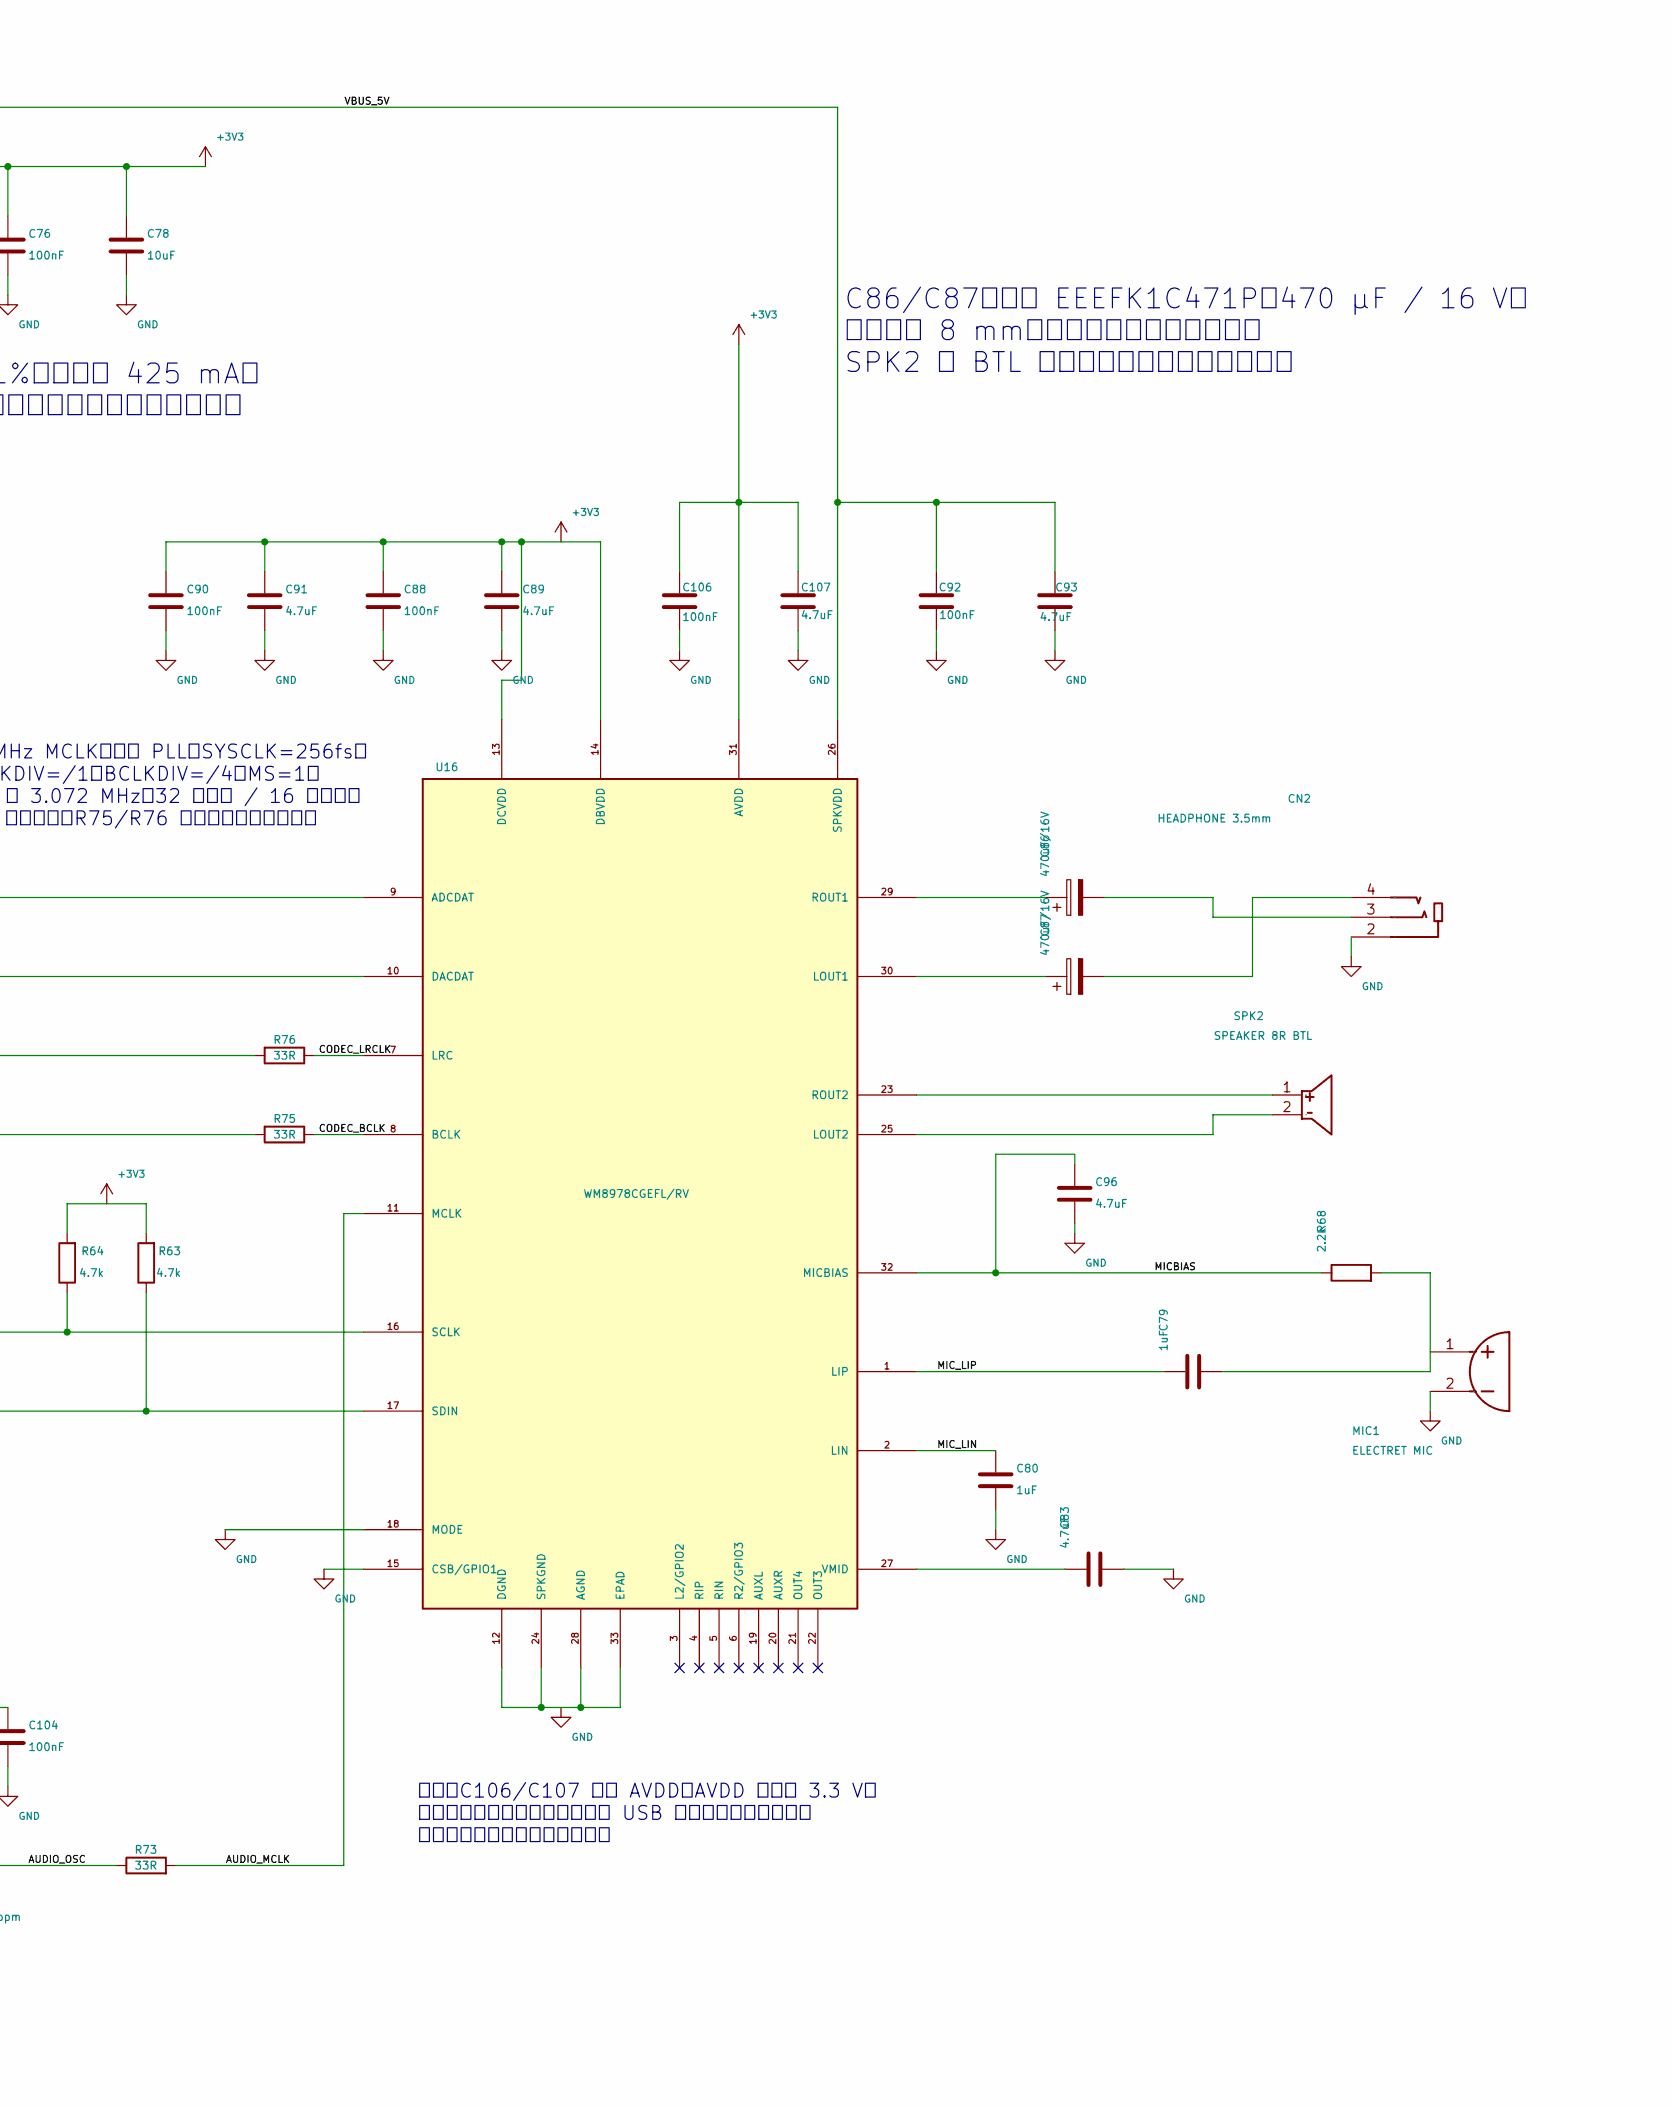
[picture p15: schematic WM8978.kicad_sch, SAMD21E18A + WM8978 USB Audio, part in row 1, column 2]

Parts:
C75, C76, C88, C90, C92, C97, C99, C102, C104, C106: 100nF; C_0603_1608Metric; Voltage 16V
C77, C83, C89, C91, C93, C96, C107: 4.7uF; C_0603_1608Metric; Voltage 16V
C78: 10uF; C_0603_1608Metric; Voltage 16V
C79, C80, C105: 1uF; C_0603_1608Metric; Voltage 16V
C86, C87: 470uF/16V; CP_Elec_8x10.5; MPN EEEFK1C471P
C98, C100: 10uF / 16V; C_0603_1608Metric; Voltage 16V
C101: 1uF / 16V; C_0603_1608Metric; Voltage 16V
C103: 10nF; C_0603_1608Metric; Voltage 16V
CN2: HEADPHONE 3.5mm; AUDIO-TH_PJ-3136-B; MPN PJ-3136-B
D1, D2: PESD5V0U1BA; D_SOD-323
J2: JLINK SWD; JST_XH_B4B-XH-A_1x04_P2.50mm_Vertical; MPN B4B-XH-A(LF)(SN)
MIC1: ELECTRET MIC; MIC-TH_BD4.0-P1.40-D0.4-L-FD
R53, R54: 22R; R_0603_1608Metric
R63, R64: 4.7k; R_0603_1608Metric
R65, R66: 5.1k; R_0603_1608Metric
R68: 2.2k; R_0603_1608Metric
R70: 10k; R_0603_1608Metric
R71: 1k; R_0603_1608Metric
R73: 33R; R_0603_1608Metric
R74: 100k; R_0603_1608Metric
R75, R76: 33R; R_0603_1608Metric; Tolerance 1%
R78: 61.9k; R_0603_1608Metric; Tolerance 1%
SPK2: SPEAKER 8R BTL; JST_PH_B2B-PH-K_1x02_P2.00mm_Vertical
U1: ATSAMD21E18A-A; TQFP-32_7x7mm_P0.8mm; MPN ATSAMD21E18A-AU
U15: TLV1117LV33DCYR; SOT-223; MPN TLV1117LV33DCYR
U16: WM8978CGEFL/RV; QFN-32-1EP_5x5mm_P0.5mm_EP3.45x3.45mm; MPN WM8978CGEFL/RV
U17: TPS2553DBVR; SOT-23-6; MPN TPS2553DBVR
USB2: USB-C USB2 DEVICE; USB_C_GCT_USB4105_GF_A; MPN USB4105-GF-A
Y1: 12MHz / 3.3V / 50ppm; Oscillator_SMD_Abracon_ASE-4Pin_3.2x2.5mm; MPN ASE-12.000MHZ-LC-T
Y2: 12.288MHz / 3.3V / 50ppm; Oscillator_SMD_Abracon_ASE-4Pin_3.2x2.5mm; MPN ASE-12.288MHZ-L-C-T

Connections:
+3V3: C76.1, C78.1, C88.1, C89.1, C90.1, C91.1, C97.1, C98.1, C99.1, C100.1, C103.1, C104.1, C106.1, C107.1, J2.1, R63.2, R64.2, R70.1, R71.1, U1.9 (VDDANA), U1.30 (VDDIN), U15.2 (VOUT), U15.4 (TAB), U16.13 (DCVDD), U16.14 (DBVDD), U16.31 (AVDD), Y1.4 (Vdd), Y2.4 (Vdd)
/AUDIO_CLK_EN: R74.1, U1.19 (PA18_/_XO_EN), Y1.1 (EN), Y2.1 (EN)
/AUDIO_MCLK: R73.2, U16.11 (MCLK)
/AUDIO_OSC: R73.1, Y2.3 (OUT)
/CODEC_BCLK: R75.1, U16.8 (BCLK)
/CODEC_LRCLK: R76.1, U16.7 (LRC)
/CODEC_SCL: R64.1, U1.22 (PA23_/_SCL), U16.16 (SCLK)
/CODEC_SDA: R63.1, U1.21 (PA22_/_SDA), U16.17 (SDIN)
/I2S_ADCDAT: U1.11 (PA08_/_I2S_RX), U16.9 (ADCDAT)
/I2S_BCLK: R75.2, U1.13 (PA10_/_SCK0)
/I2S_DACDAT: U1.8 (PA07_/_I2S_TX), U16.10 (DACDAT)
/I2S_LRCLK: R76.2, U1.14 (PA11_/_FS0)
/MCU_12M: U1.15 (PA14_/_XIN), Y1.3 (OUT)
/MCU_RESET_N: C102.1, R70.2, U1.26 (~RESET)
/MICBIAS: C96.1, R68.1, U16.32 (MICBIAS)
/MIC_LIN: C80.1, U16.2 (LIN)
/MIC_LIP: C79.1, U16.1 (LIP)
/SWCLK: J2.3, R71.2, U1.31 (PA30_/_SWCLK)
/SWDIO: J2.2, U1.32 (PA31_/_SWDIO)
/USB_DM: R54.2, U1.23 (PA24_/_USB_DM)
/USB_DP: R53.2, U1.24 (PA25_/_USB_DP)
/VBUS_5V: C75.1, C77.1, C92.2, C93.2, U15.3 (VIN), U16.26 (SPKVDD), U17.6 (OUT)
/VBUS_RAW: C105.1, U17.1 (IN), U17.3 (EN), USB2.A4 (VBUS), USB2.A9 (VBUS), USB2.B4 (VBUS), USB2.B9 (VBUS)
/VDDCORE: C101.1, U1.29 (VDDCORE)
GND: C75.2, C76.2, C77.2, C78.2, C80.2, C83.2, C88.2, C89.2, C90.2, C91.2, C92.1, C93.1, C96.2, C97.2, C98.2, C99.2, C100.2, C101.2, C102.2, C103.2, C104.2, C105.2, C106.2, C107.2, CN2.2, D1.2 (A2), D2.2 (A2), J2.4, MIC1.2, R65.2, R66.2, R74.2, R78.2, U1.10 (GND), U1.28 (GND), U15.1 (GND), U16.12 (DGND), U16.15 (CSB/GPIO1), U16.18 (MODE), U16.24 (SPKGND), U16.28 (AGND), U16.33 (EPAD), U17.2 (GND), USB2.1 (GND_/_SHIELD), USB2.2 (GND_/_SHIELD), USB2.3 (GND_/_SHIELD), USB2.4 (GND_/_SHIELD), USB2.A1 (GND_/_SHIELD), USB2.A12 (GND_/_SHIELD), USB2.B1 (GND_/_SHIELD), USB2.B12 (GND_/_SHIELD), Y1.2 (GND), Y2.2 (GND)
unnamed: C79.2, MIC1.1, R68.2
unnamed: C86.2, CN2.3
unnamed: C87.2, CN2.4
unnamed: D1.1 (A1), R53.1, USB2.A6 (D+), USB2.B6 (D+)
unnamed: D2.1 (A1), R54.1, USB2.A7 (D-), USB2.B7 (D-)
unnamed: C87.1, U16.30 (LOUT1)
unnamed: SPK2.2, U16.25 (LOUT2)
unnamed: C86.1, U16.29 (ROUT1)
unnamed: SPK2.1, U16.23 (ROUT2)
unnamed: C83.1, U16.27 (VMID)
unnamed: R78.1, U17.5 (ILIM)
unnamed: R65.1, USB2.A5 (CC1)
unnamed: R66.1, USB2.B5 (CC2)

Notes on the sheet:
固件：核对 SAMD21 硅版本（C/D/H），遵循 DS80000760 勘误。 USB 异步音频需反馈及 DMA 缓冲；本工程未提供固件。 USB 配置完成前关闭扬声器；整机持续电流不超过 350 mA， 并满足 USB 主机供电预算；挂起电流需实板验证。
USB 输入：R78 = 61.9 kΩ / 1%，限流约 425 mA。 C105 = 1 µF，直接接 VBUS；输出电容位于软启动开关之后。
编解码器使用 Y2 的 12.288 MHz MCLK，关闭 PLL；SYSCLK=256fs。 R6：CLKSEL=MCLK，MCLKDIV=/1，BCLKDIV=/4，MS=1。 LRCLK 为 48 kHz，BCLK 为 3.072 MHz；32 位时隙 / 16 位采样。 SAMD21 的 I2S 时钟单元 0 设为从机；R75/R76 靠近编解码器输出端。
C86/C87：松下 EEEFK1C471P，470 µF / 16 V。 罐体直径 8 mm；正极朝向音频编解码器。 SPK2 为 BTL 桥接输出，两端均不可接地。
布局：C106/C107 靠近 AVDD；AVDD 直接接 3.3 V。 使用连续完整的地平面；时钟和 USB 走线远离麦克风输入， 耳机回流路径避开麦克风电路。
使用 OSC8M 启动 → PA18 拉高 → 等待至少 2 ms → 切换至 12 MHz XOSC 外部时钟。 Y1 为单片机及 USB 提供时钟；Y2 的 12.288 MHz 仅供编解码器，编解码器为 I2S 主机。 USB 与音频时钟异步，需使用反馈及 DMA 缓冲。 挂起前：先静音，将单片机切回内部时钟，再关闭 Y1/Y2。
J2 引脚：1=VTref，2=SWDIO，3=SWCLK，4=GND。 四线 SWD 接口，未引出外部复位；必要时断电重启。
信号采用连续导线连接，标签仅作标注；电源和地使用常规符号。
SAMD21E18A + WM8978 | USB 全双工音频 | 48 kHz / 16 位

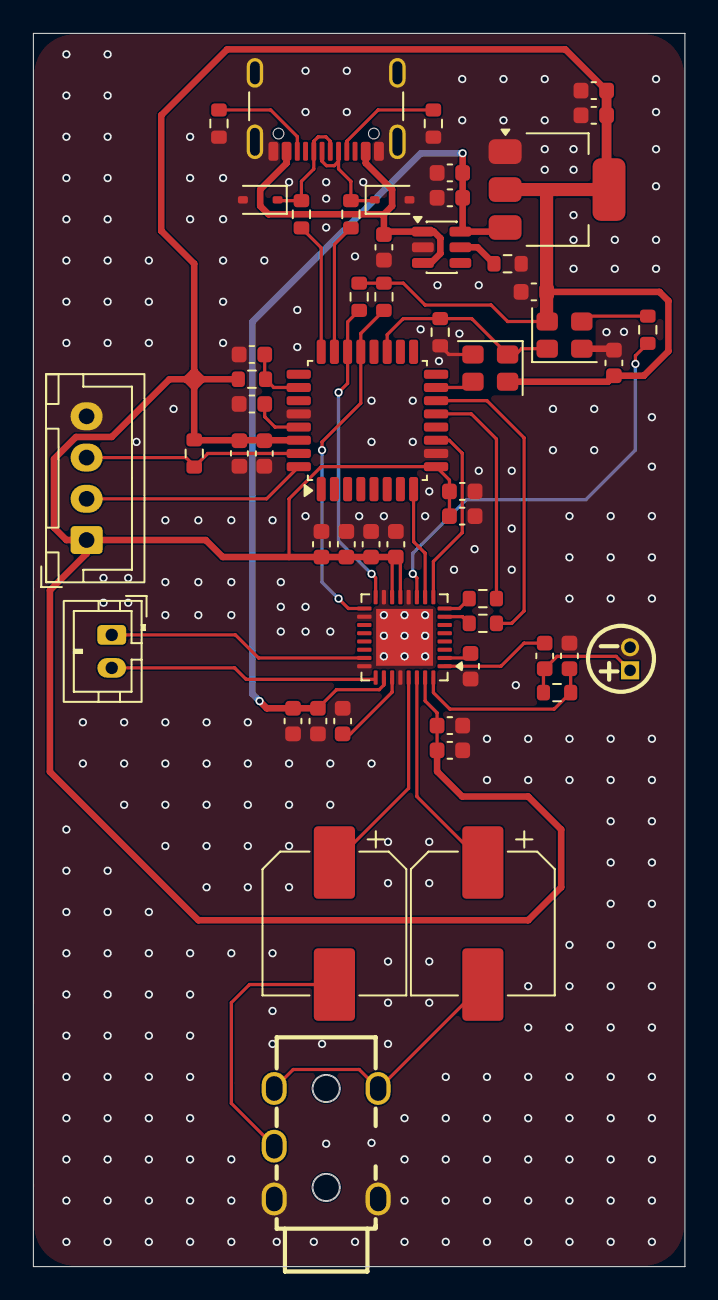
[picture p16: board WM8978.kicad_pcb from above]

Board: 2 copper layers, 39.5 x 74.8 mm, 54 parts (0 on the bottom side), 38 nets.

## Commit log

2026-09-19 Initial commit: WM8978 USB audio project
    [WM8978.kicad_pcb, WM8978.kicad_sch]
2026-09-20 Refactor schematic into functional hierarchy
    Split USB power, STM32, WM8978, and audio outputs into separate sheets; correct power decoupling and regulator specification; document the reviewed signal chain; remove the obsolete firmware tree.
    [01_usb_power.kicad_sch, 02_stm32.kicad_sch, 03_wm8978.kicad_sch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]
2026-09-21 部分修改
    [01_usb_power.kicad_sch, 02_stm32.kicad_sch, 03_wm8978.kicad_sch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]
2026-09-21 修复原理图电源网络并更新项目文档
    [01_usb_power.kicad_sch, 02_stm32.kicad_sch, 03_wm8978.kicad_sch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]
2026-09-21 更新单页原理图布局并同步 PCB
    [WM8978.kicad_pcb, WM8978.kicad_sch]
2026-09-23 更新双时钟音频工程并整理中文原理图与检查资料
    [WM8978.kicad_pcb, WM8978.kicad_sch]
2026-09-23 更新 PCB 布局、走线与铺铜
    [WM8978.kicad_pcb]
2026-10-02 更新 PCB 布局并同步复核资料
    [WM8978.kicad_pcb]
2026-10-02 补齐封装关联并绑定原始 3D 模型
    补齐 C97～C100 的符号关联，Y1/Y2 使用 Abracon 原厂 STEP，MIC1 使用立创原库 STEP。
    CN2 保留现有五脚封装，仅去除原库 CAD 多余的板下插脚，并保存未经修改的六脚原文件。
    保留最新存档中的 C97/C98 位置与铺铜调整，记录 54 个器件的关联、模型及原生 STEP 验证结果。
    [WM8978.kicad_pcb, WM8978.kicad_sch]
2026-10-03 保留最新 PCB 布局存档并更新模型检查记录
    纳入 02:13 存档中的 R71 位置、供电及 SWCLK 走线调整，保留所有原始模型绑定。
    更新几何、DRC、STEP 对齐验证与 3D 预览；未连接项和原理图一致性问题均为零，DRC 类型及数量不变。
    [WM8978.kicad_pcb]
2026-10-03 精简项目介绍与 3D 模型文档
2026-10-03 修复 README 的 3D 预览图片引用
